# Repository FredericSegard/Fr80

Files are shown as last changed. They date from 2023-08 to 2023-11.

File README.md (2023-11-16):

# Fr80

 ## Z80 Homebrew computer, code-named Fr80, pronounced Freddy.
This repo will contain all the elements for a complete Z80 system (Work in progress)

### The Backplane:
The goal is to first make a ubiquitous backplane that could accommodate many 8 or 16-bit architectures, including most x86 that is compatible, Z80, eZ80, z8000, 65C02, 65C816, 6809... You name it, it should handle it. The only difference is in the PCB labeling. I have labeled the breadboard header as per the PC ISA standard on row 1, row 2 is for the Z80, and row 3 is for the 65C02. The breadboard pins are pin-to-pin mapped A1-A13 on the left, and B1-B31 on the right.
 
This backplane follows the ISA power rail standard. This means the +5, ground, +12V, and -12V lanes are where they should be. However, there is provision for a -5V regulator, since most ATX PSUs no longer support it. And since 3.3V is more prevalent these days, I have assigned the -5V lane to +3.3V. However, you can select which voltage you need by simply changing a jumper's position. There is an alternate barrel jack power input for 5 volts only. There is a provision for a 3.3V regulator should you need it. Both power sources are soft power-on. Jumpers are present to repurpose the button, since electrically, they could not be tied together.

It is a passive backplane, so there should be no interference with other signal types. So in theory, you could reassign all non-power rail buses, except for the reset lane and A7 and A8. The reset circuit, which is jumper selectable between active high or active low, cannot be reassigned. And the CPU activity LED, which monitors A7 or A8 (jumper selectable), can't also be moved.

I have just received the PCBs from the fab house. I will assemble it and let you know if everything works as intended.

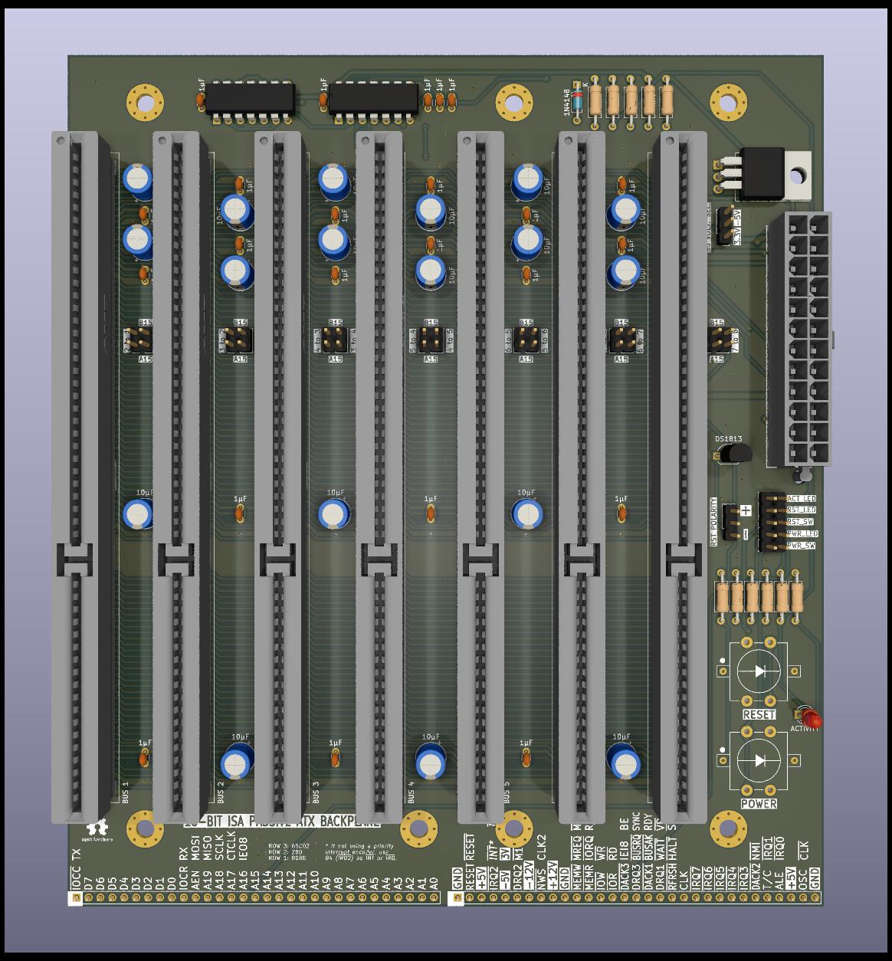
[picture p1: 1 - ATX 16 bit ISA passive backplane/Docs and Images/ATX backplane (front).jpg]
Front of board


### The Core CPU card:
I made several iterations of the CPU board, but now I'm satisfied with this revision 3. It's a very compact 100mm² 4-layer board, that contains the CPU, 128KB Flash, 512KM RAM, bank switching circuitry, a priority interrupt encoder, a CTC, and an SIO with USB ports (type A and type B).

I gave myself a challenge to fit as much as possible in a 100mm² PCB, all the while managing to put in a ZIF socket and some blinkenlights. The board is so stuffed with components, that I needed to place the bypass capacitors in the sockets, as well as some resistors. 

I will send out the Gerber for manufacturing, and keep you posted.

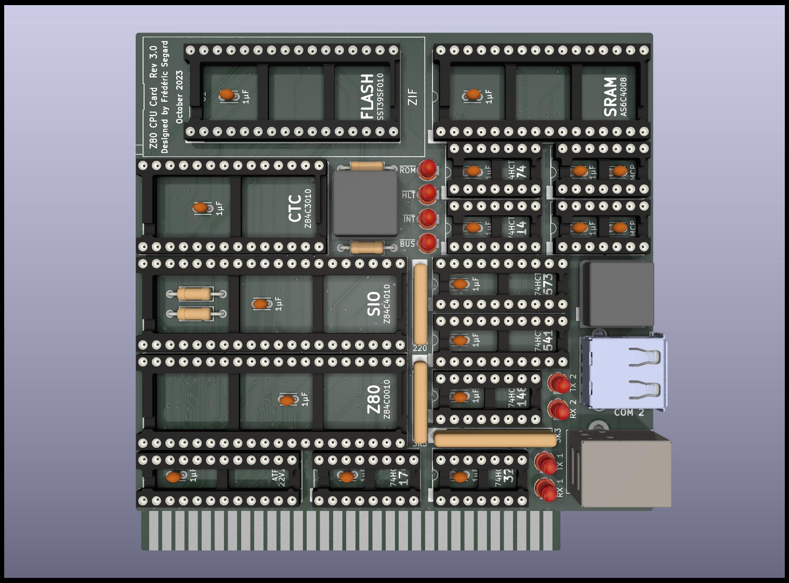
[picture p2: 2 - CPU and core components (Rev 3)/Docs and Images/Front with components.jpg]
Front of board


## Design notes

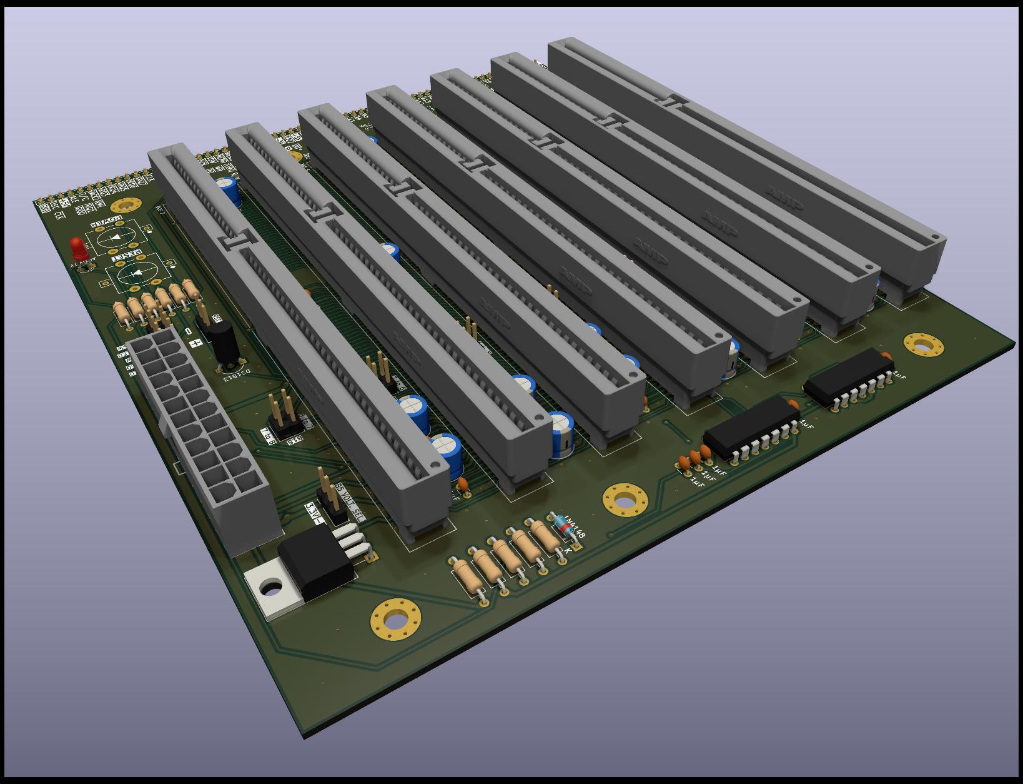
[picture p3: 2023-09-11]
1 - ATX 16 bit ISA passive backplane/Docs and Images/ATX backplane (view2).jpg

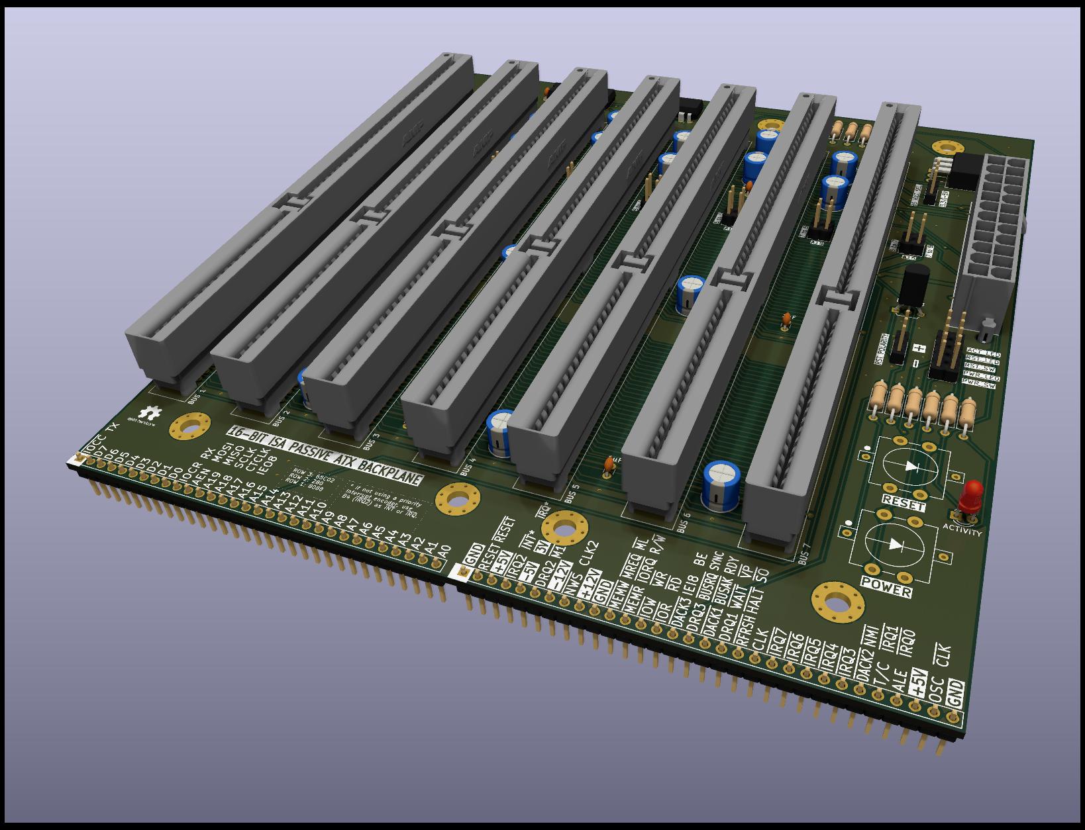
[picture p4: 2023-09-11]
1 - ATX 16 bit ISA passive backplane/Docs and Images/ATX backplane (view1).jpg

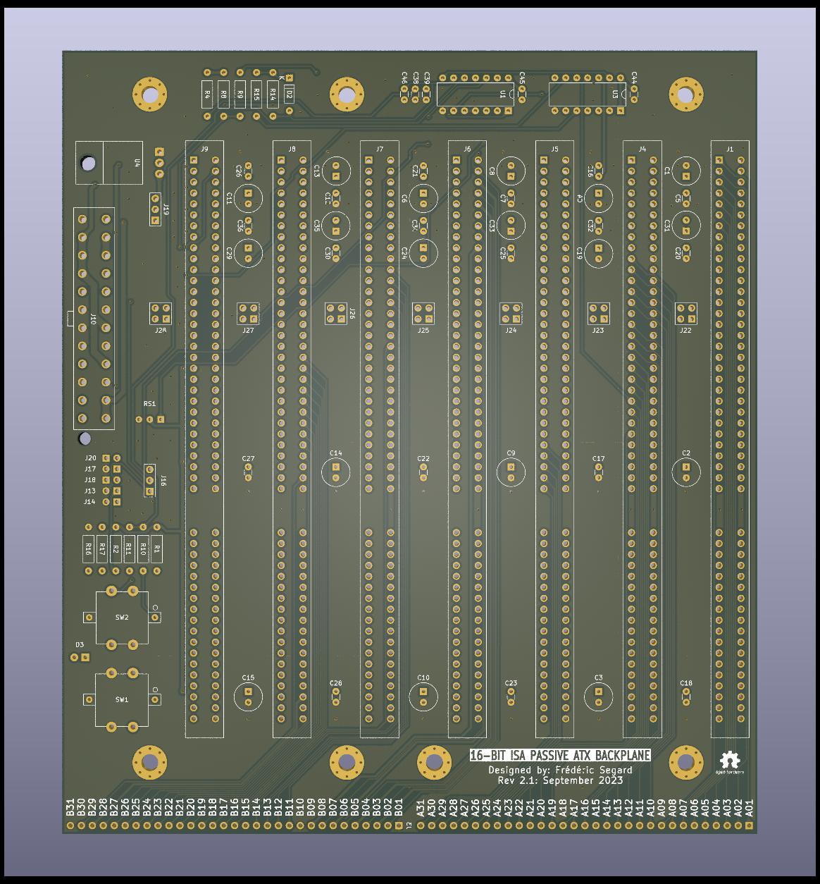
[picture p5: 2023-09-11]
1 - ATX 16 bit ISA passive backplane/Docs and Images/ATX backplane (back).jpg

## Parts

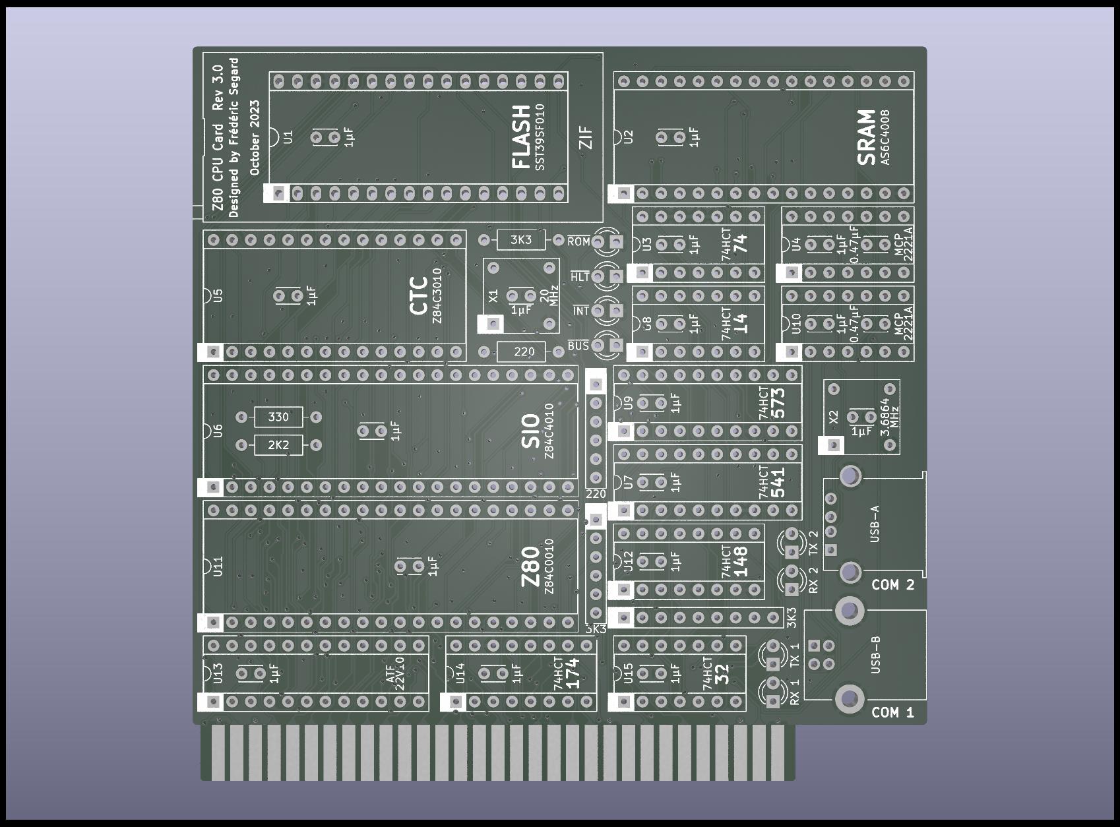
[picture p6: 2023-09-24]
2 - CPU and core components (Rev 3)/Docs and Images/Front without components.jpg

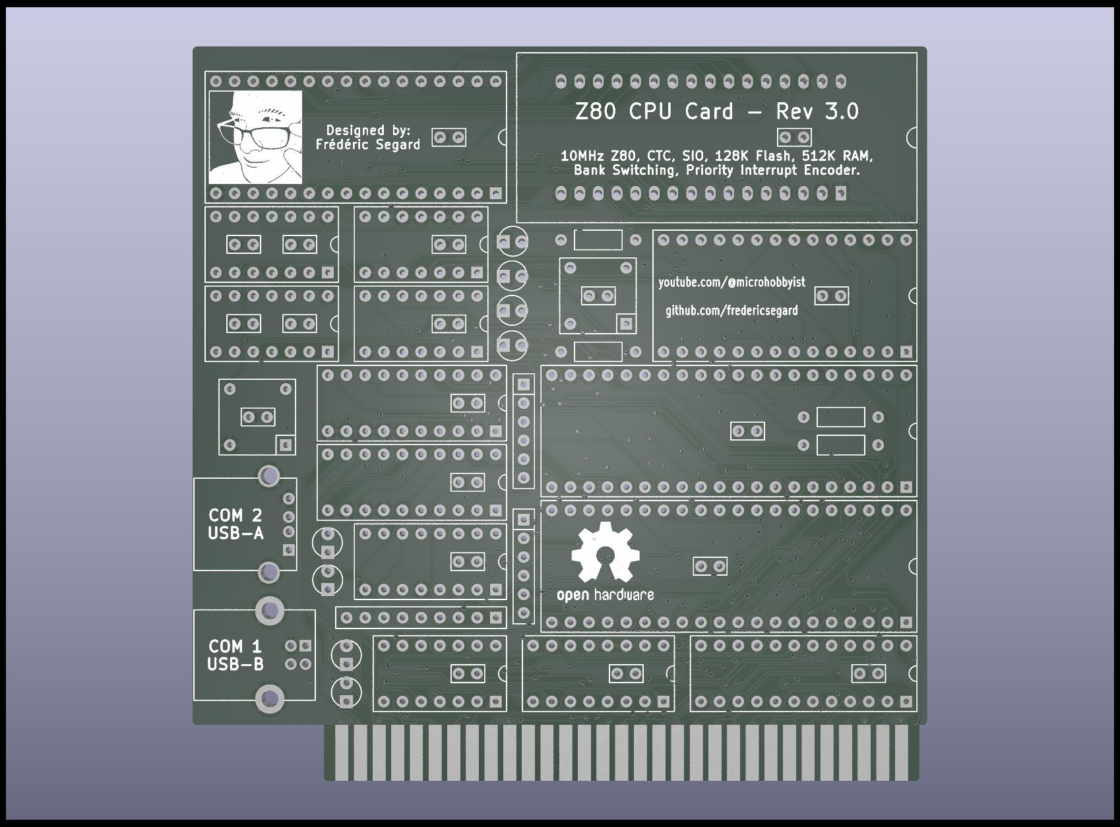
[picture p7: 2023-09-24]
2 - CPU and core components (Rev 3)/Docs and Images/Back.jpg

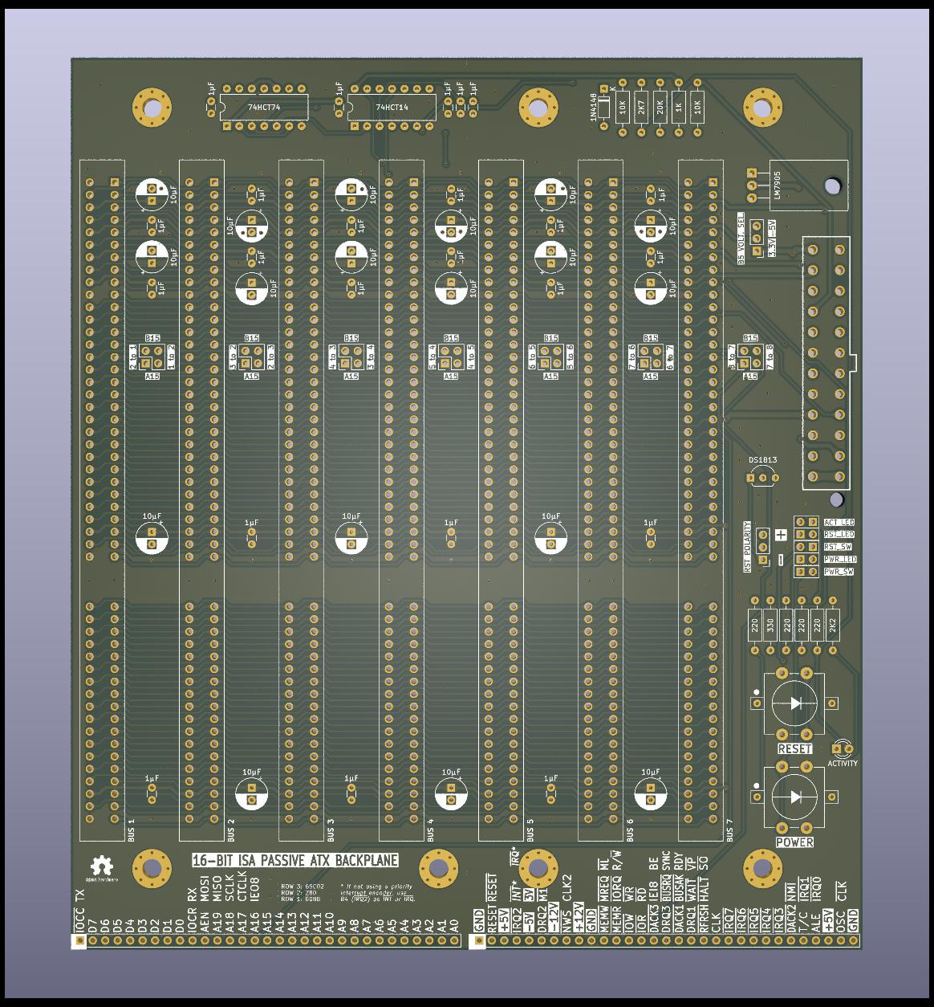
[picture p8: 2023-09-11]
1 - ATX 16 bit ISA passive backplane/Docs and Images/ATX backplane (front without parts).jpg

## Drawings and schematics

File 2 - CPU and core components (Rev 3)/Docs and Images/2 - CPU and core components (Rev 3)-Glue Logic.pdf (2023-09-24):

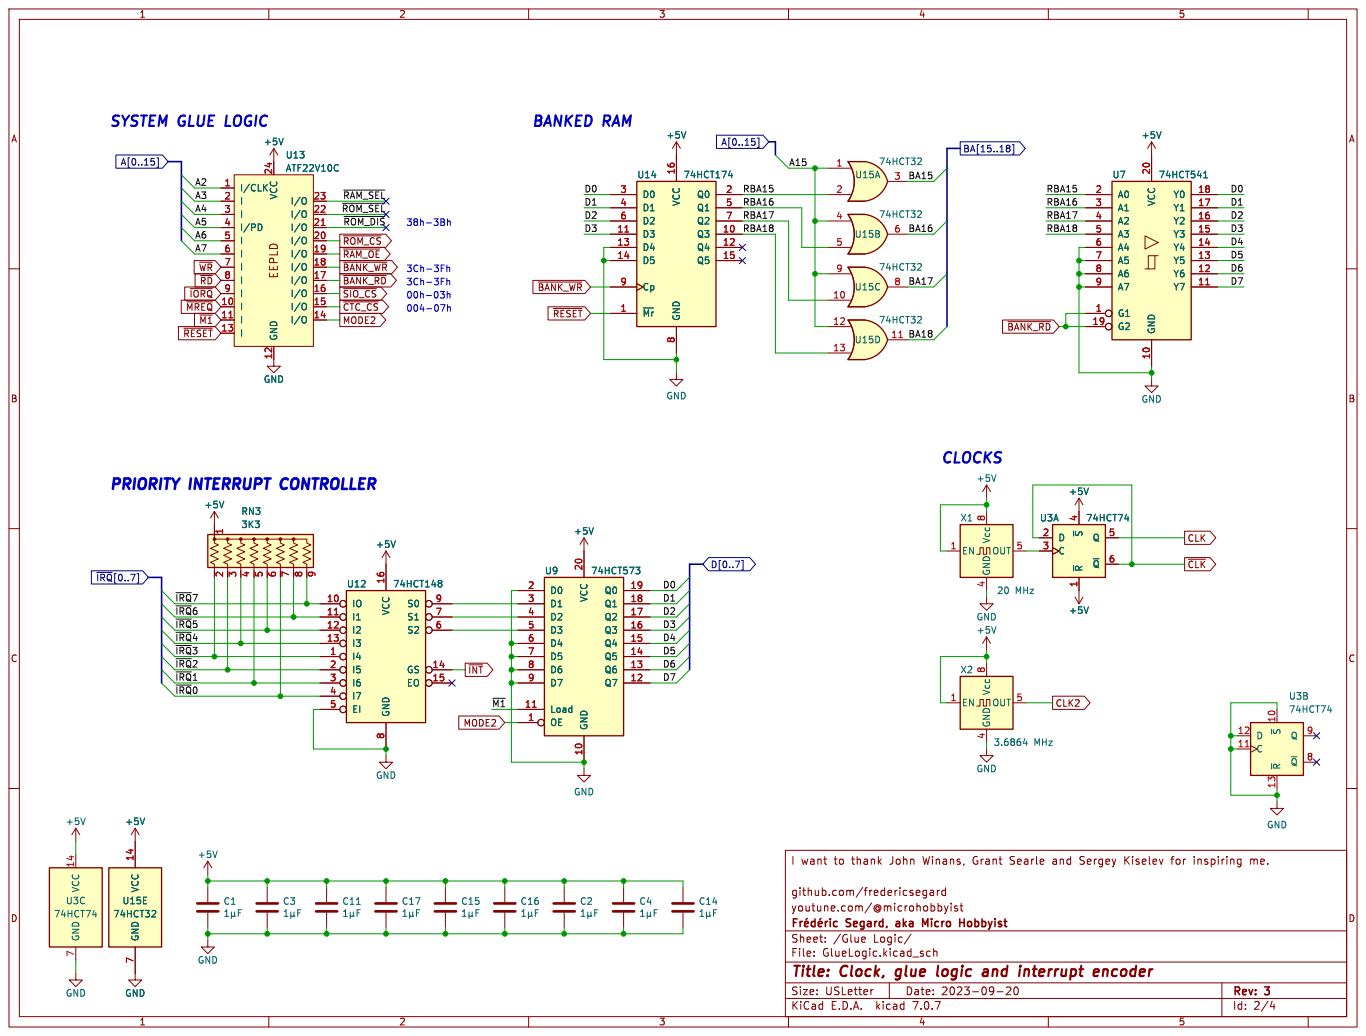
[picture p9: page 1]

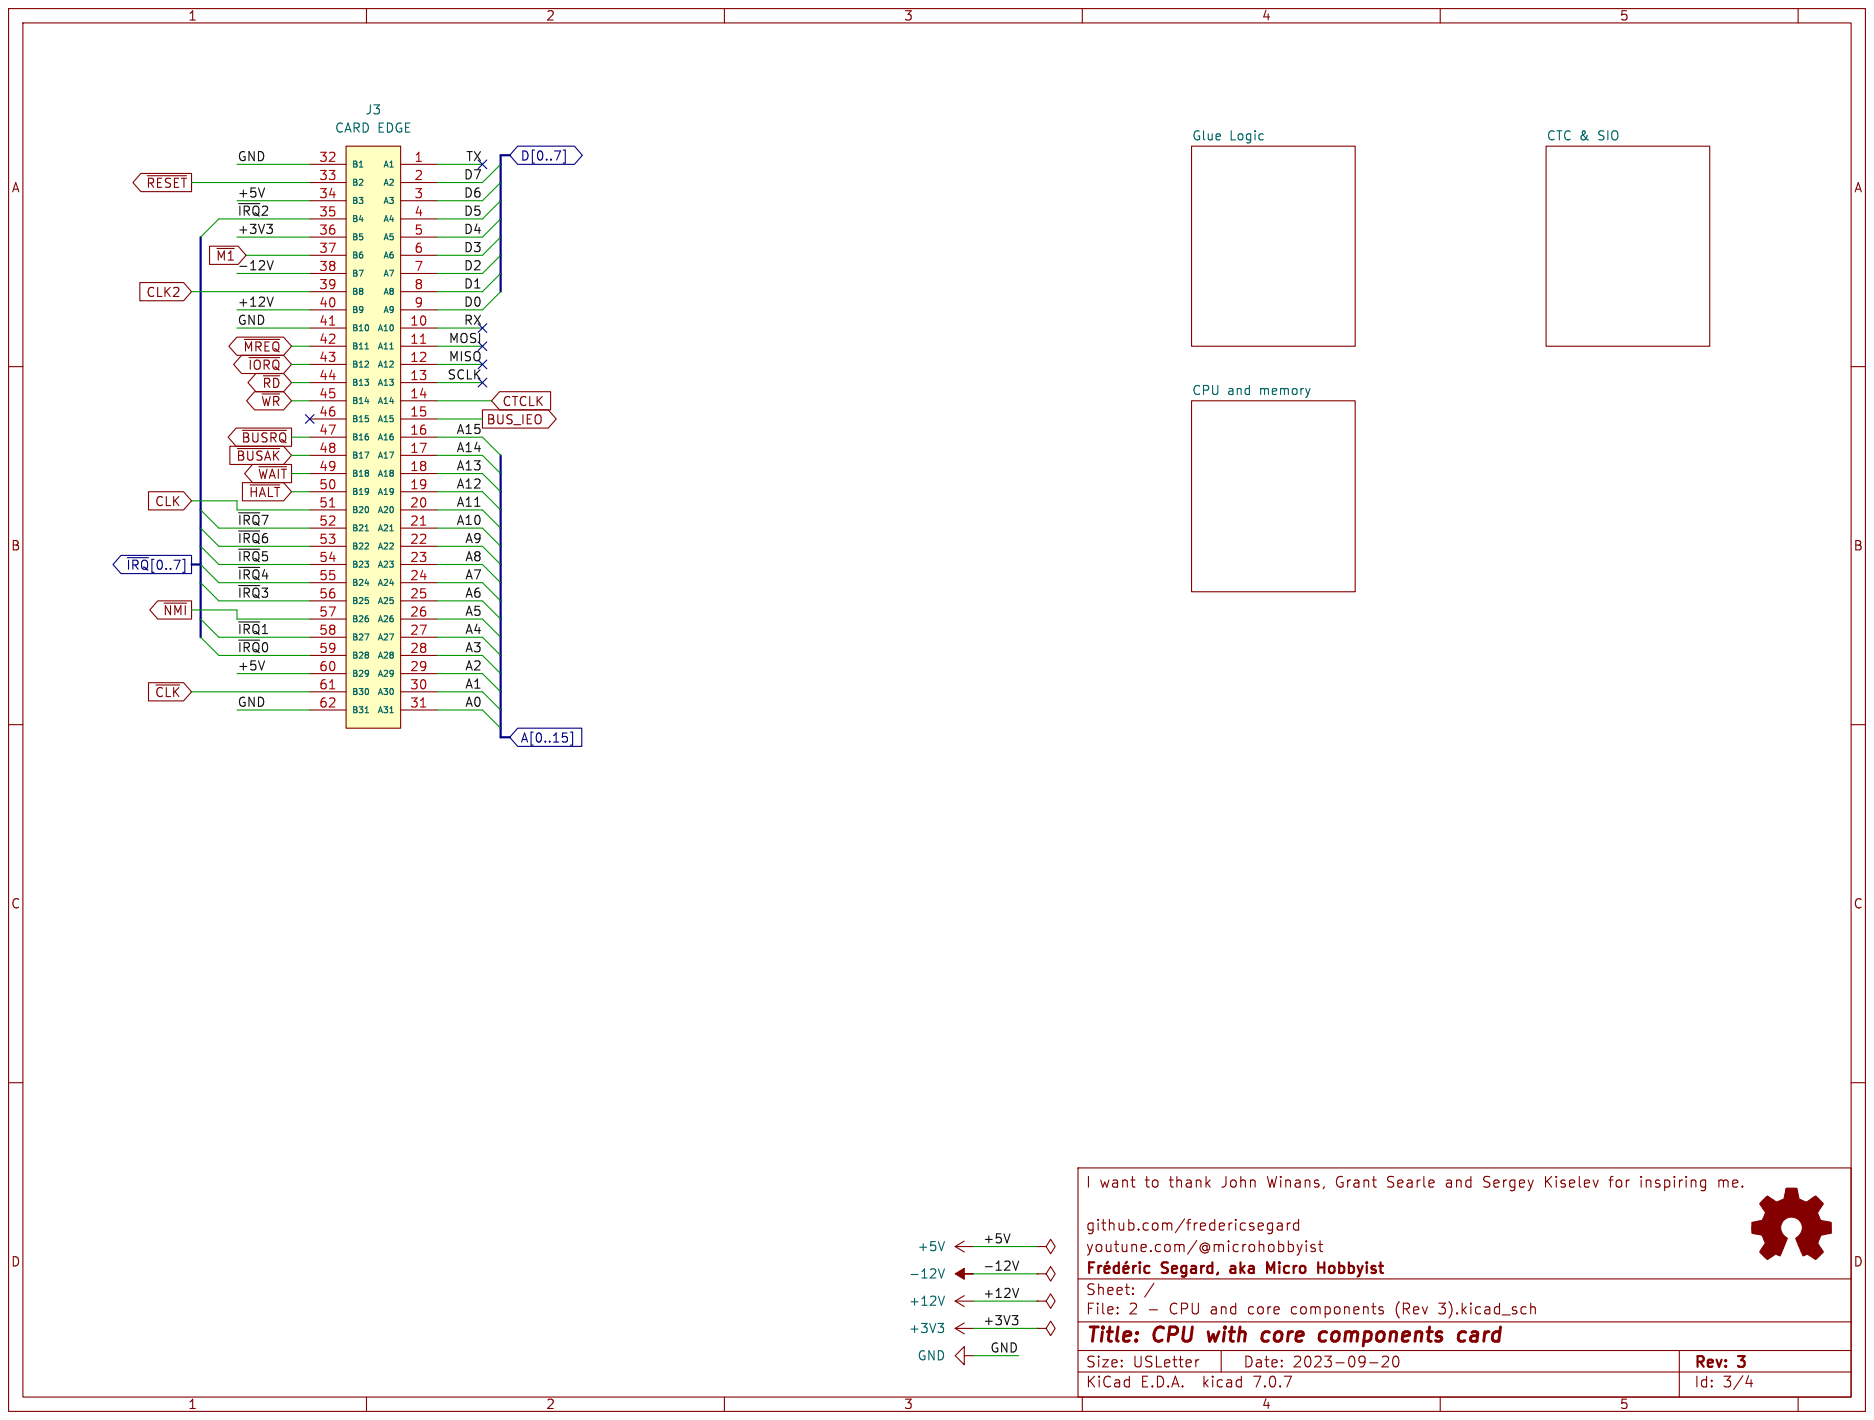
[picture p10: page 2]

Id: 3/4 Title: CPU with core components card

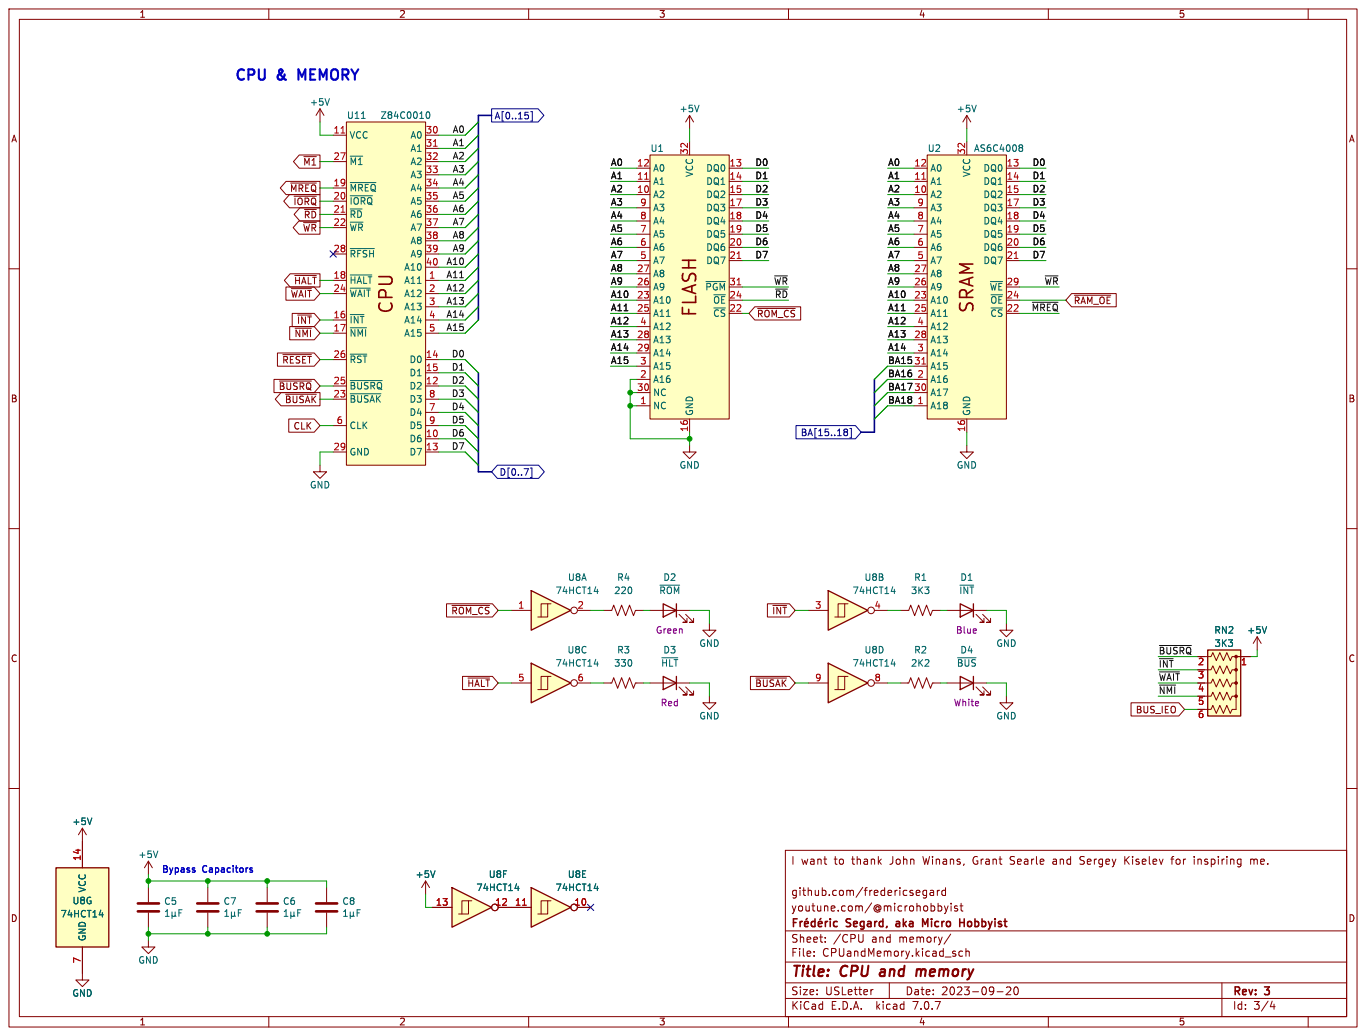
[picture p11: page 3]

github.com/fredericsegard
youtune.com/@microhobbyist
Id: 3/4 Title: CPU and memory

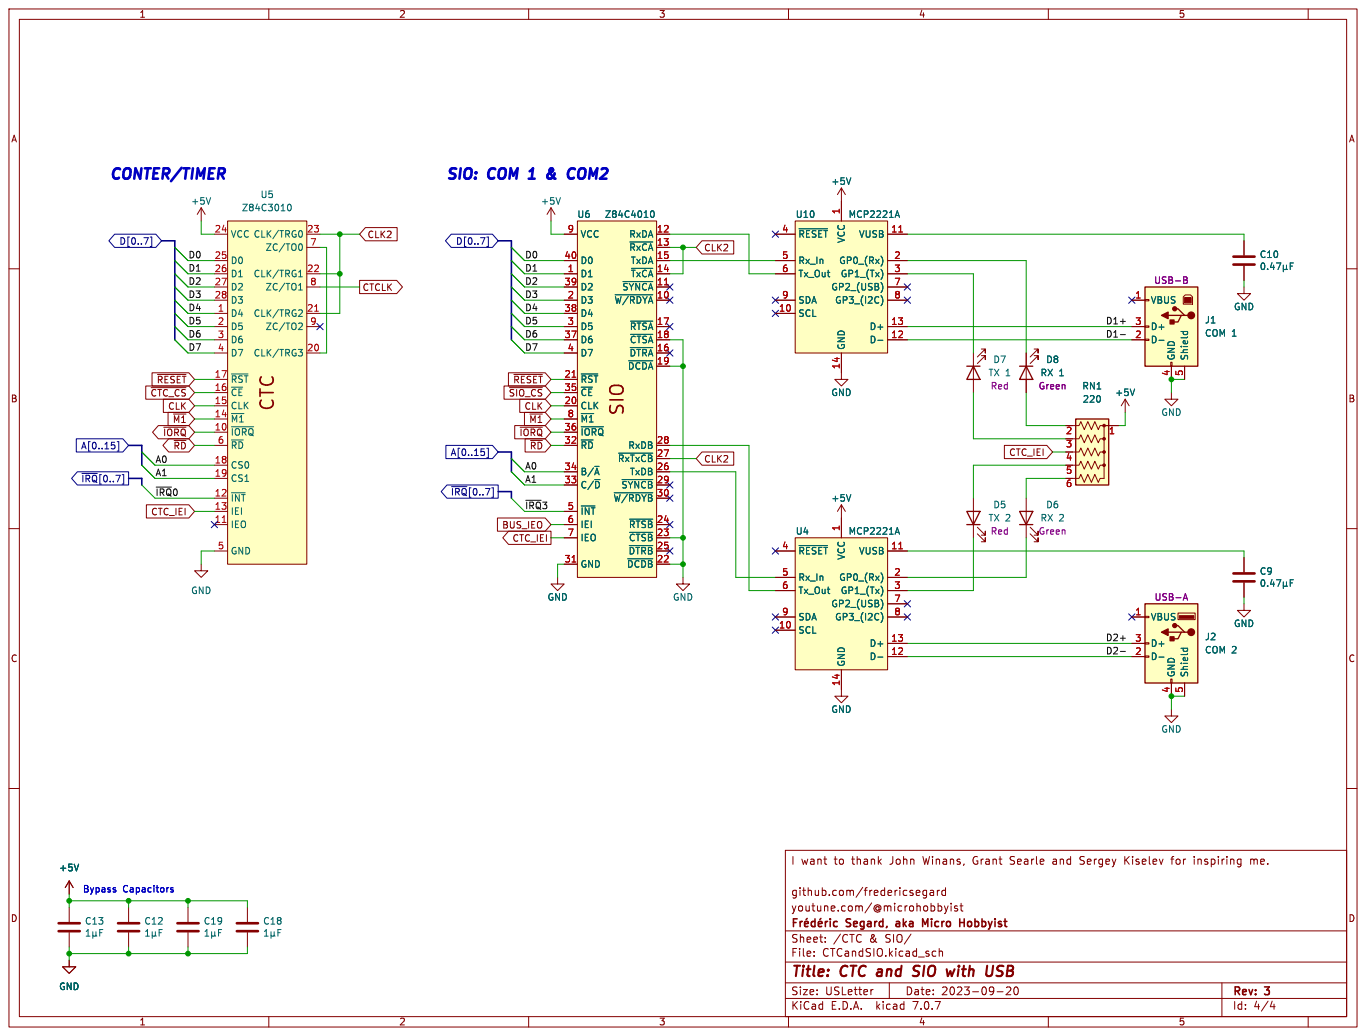
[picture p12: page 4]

þÿ0.47µF D8 RX 1 Green GND

Id: 4/4 Title: CTC and SIO with USB

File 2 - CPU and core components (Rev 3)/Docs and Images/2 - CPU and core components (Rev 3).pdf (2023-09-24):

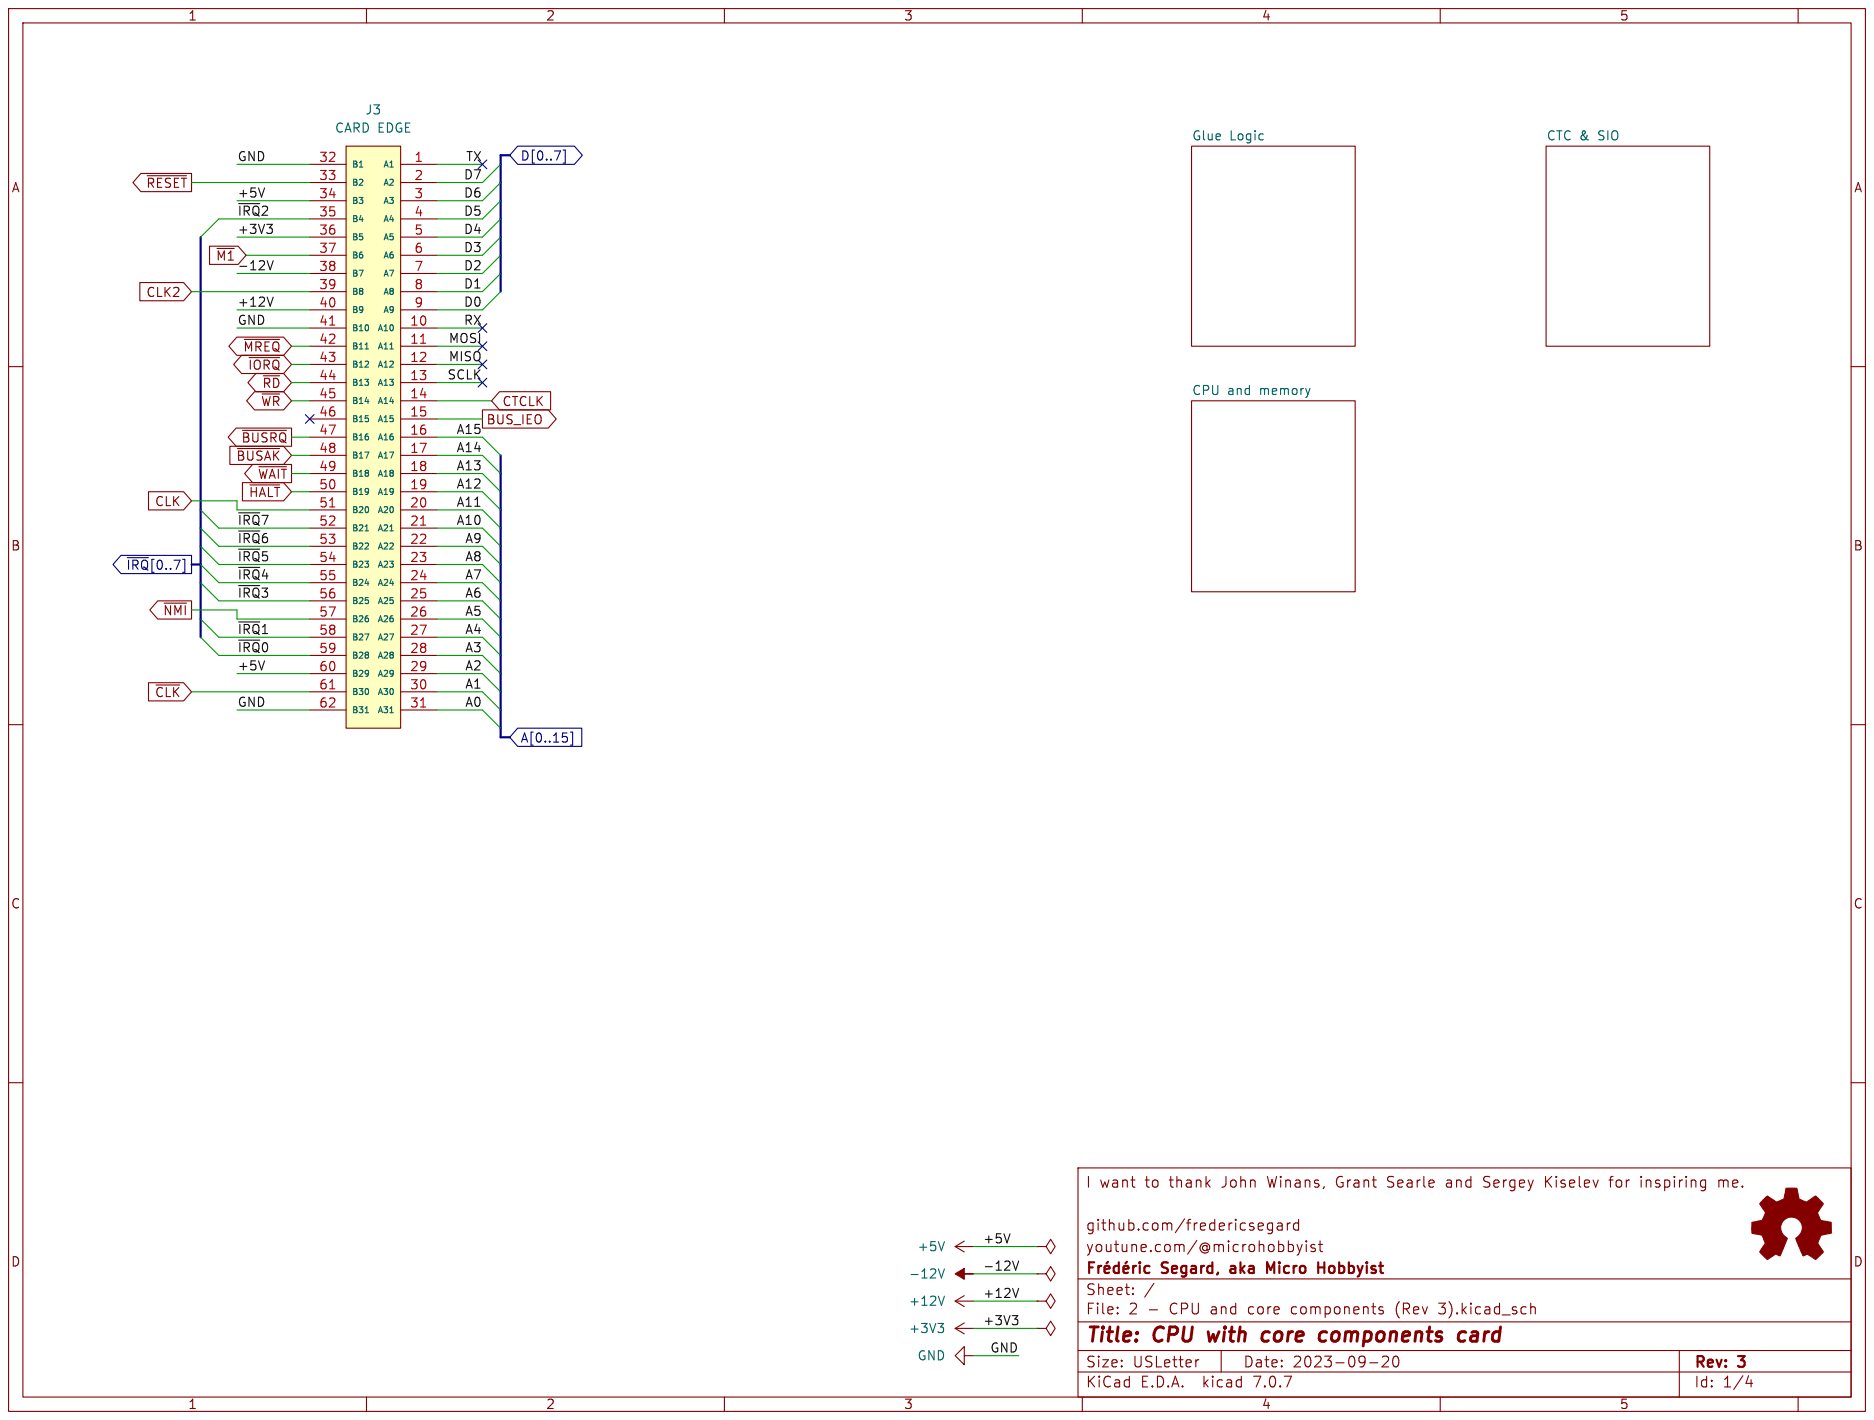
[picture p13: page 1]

Id: 1/4 Title: CPU with core components card

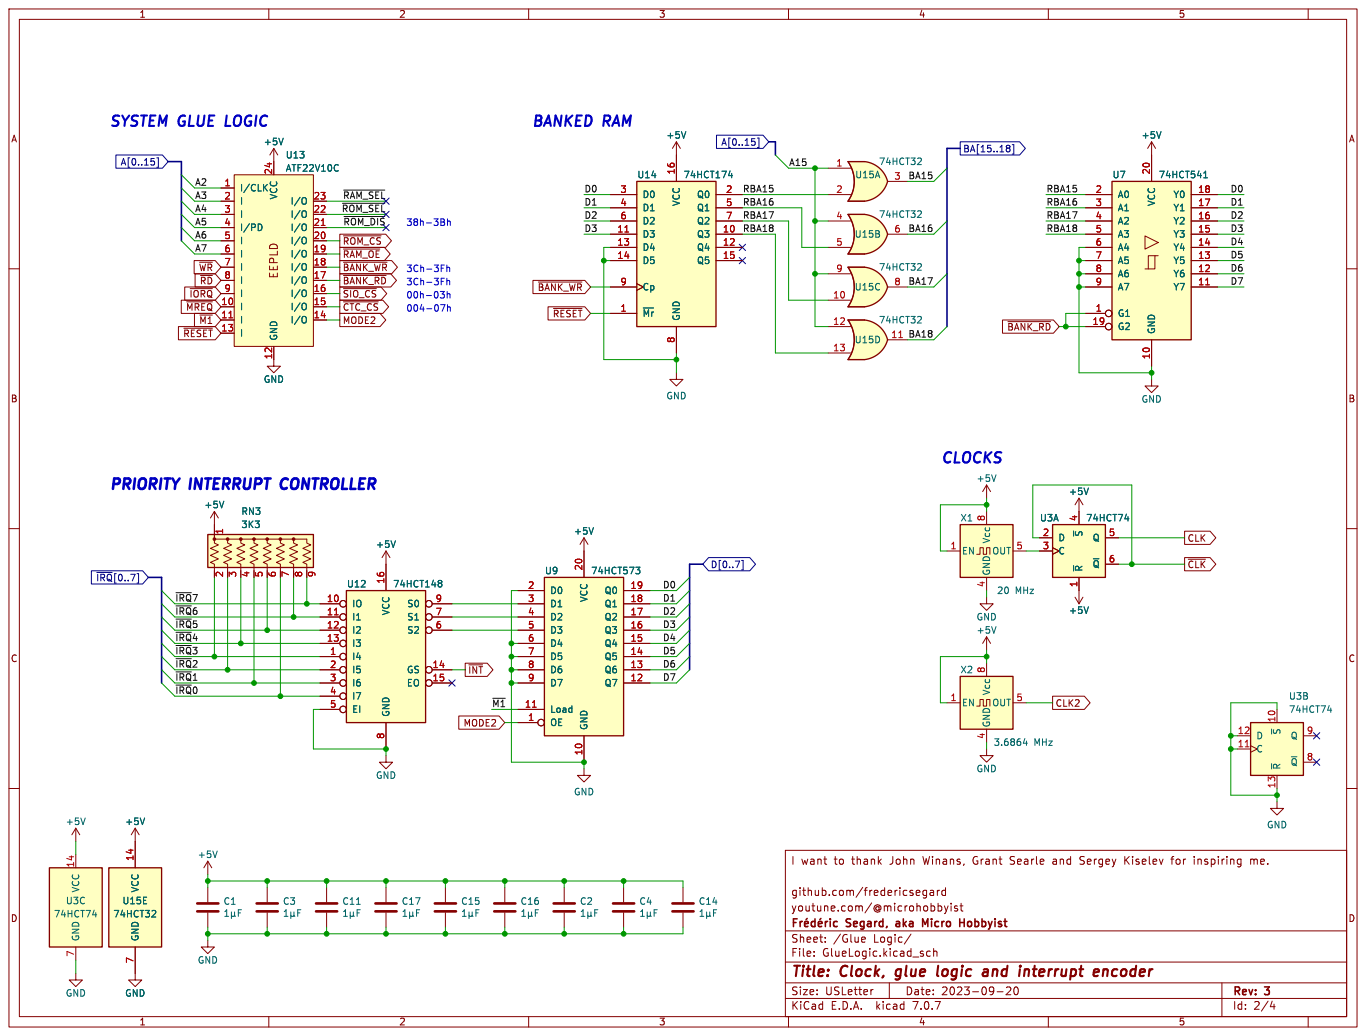
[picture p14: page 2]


github.com/fredericsegard
youtune.com/@microhobbyist
Id: 3/4 Title: CPU and memory


þÿ0.47µF D8 RX 1 Green GND

Id: 4/4 Title: CTC and SIO with USB

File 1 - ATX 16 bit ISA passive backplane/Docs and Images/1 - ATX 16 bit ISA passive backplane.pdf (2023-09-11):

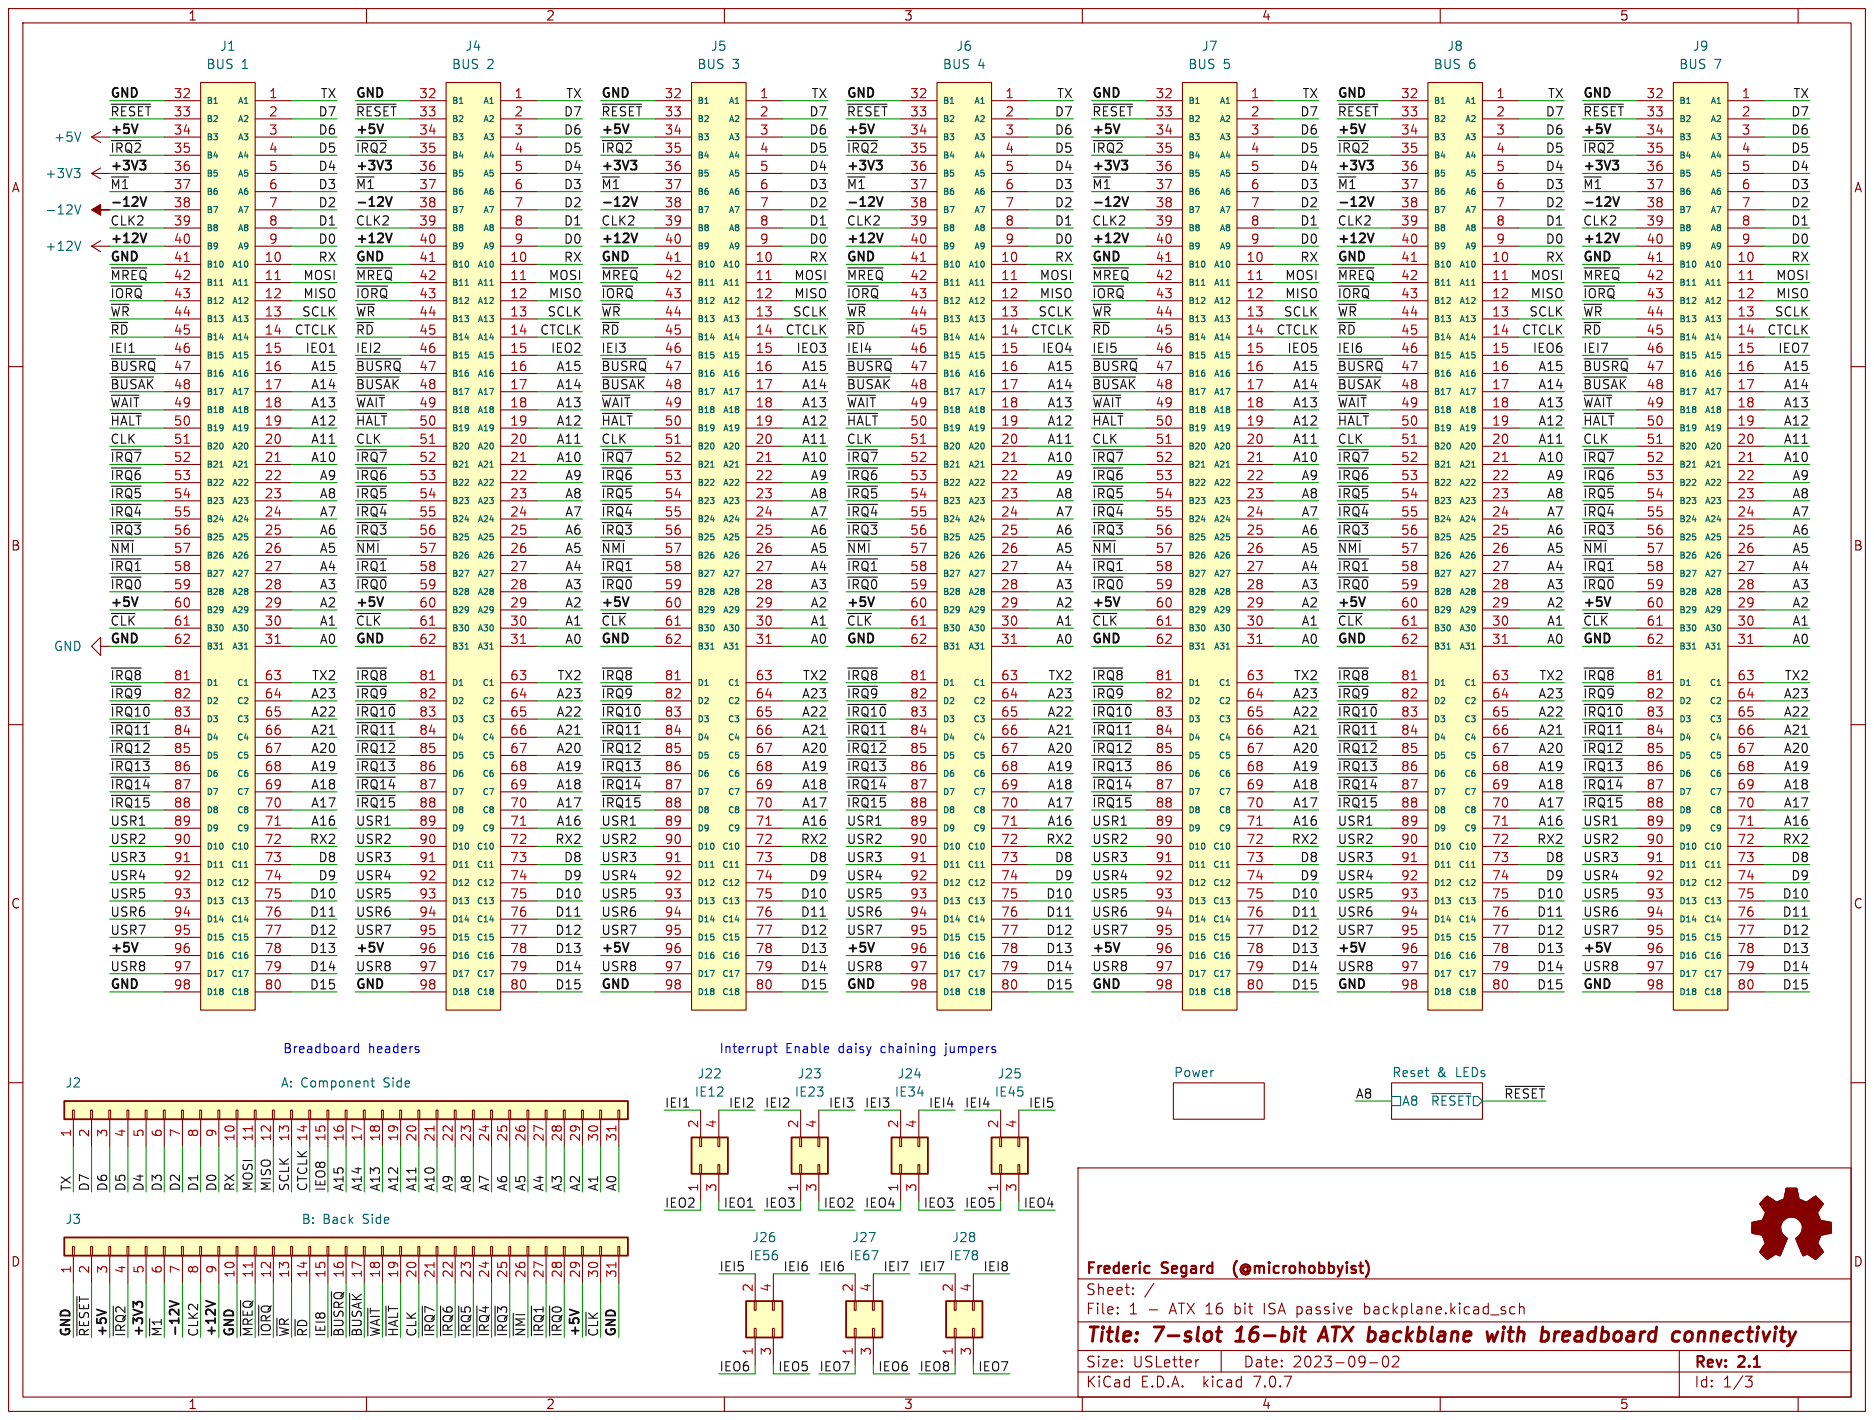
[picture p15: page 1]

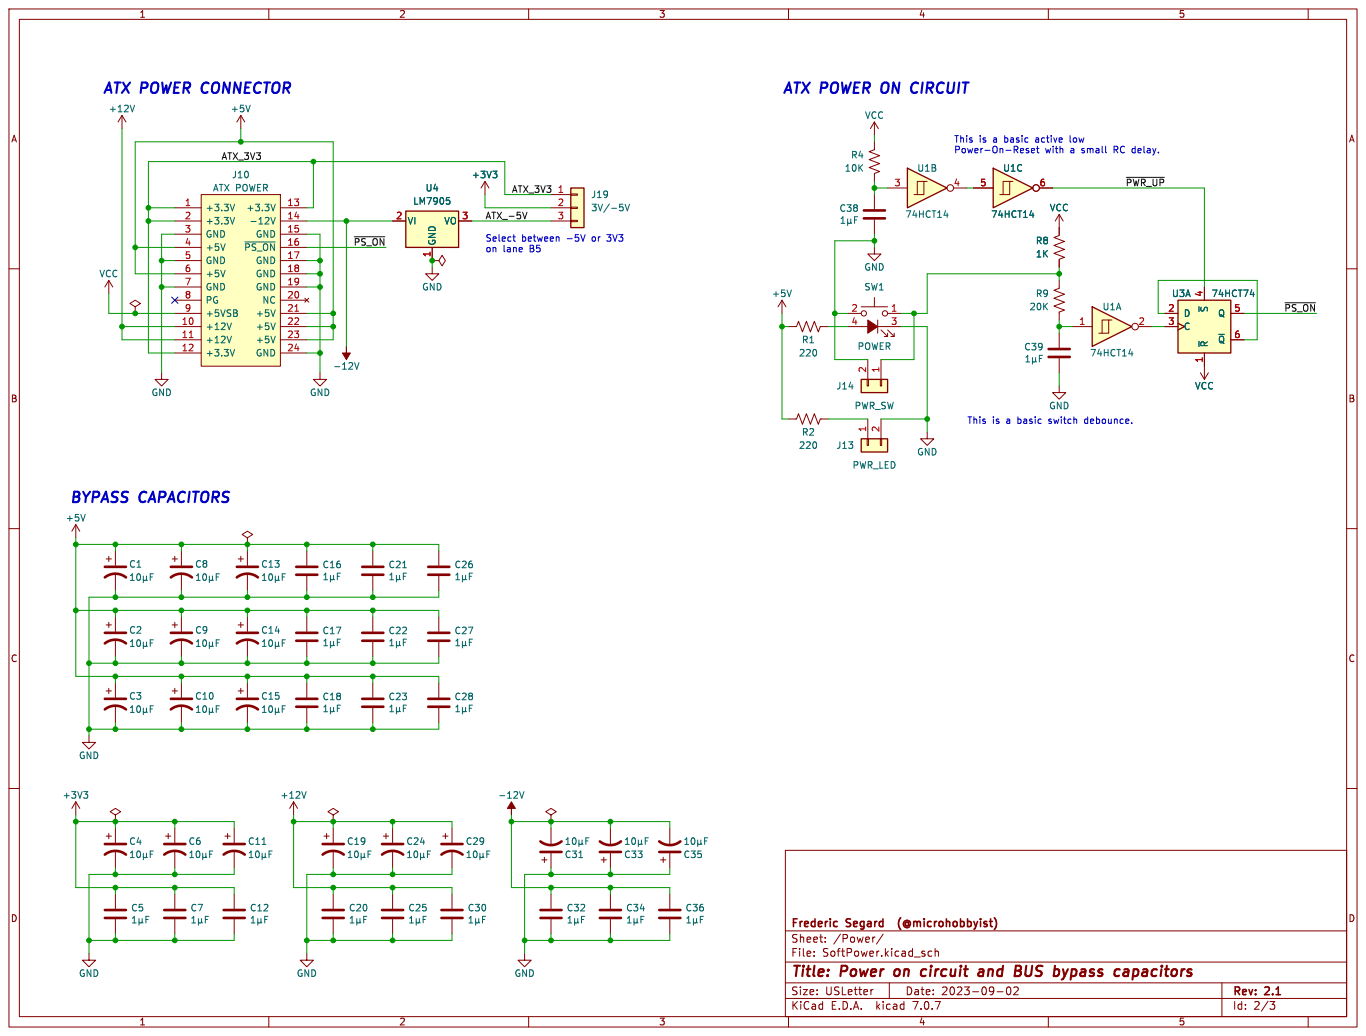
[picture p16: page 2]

This is a basic switch debounce. ATX POWER ON CIRCUIT

Id: 2/3 Title: Power on circuit and BUS bypass capacitors

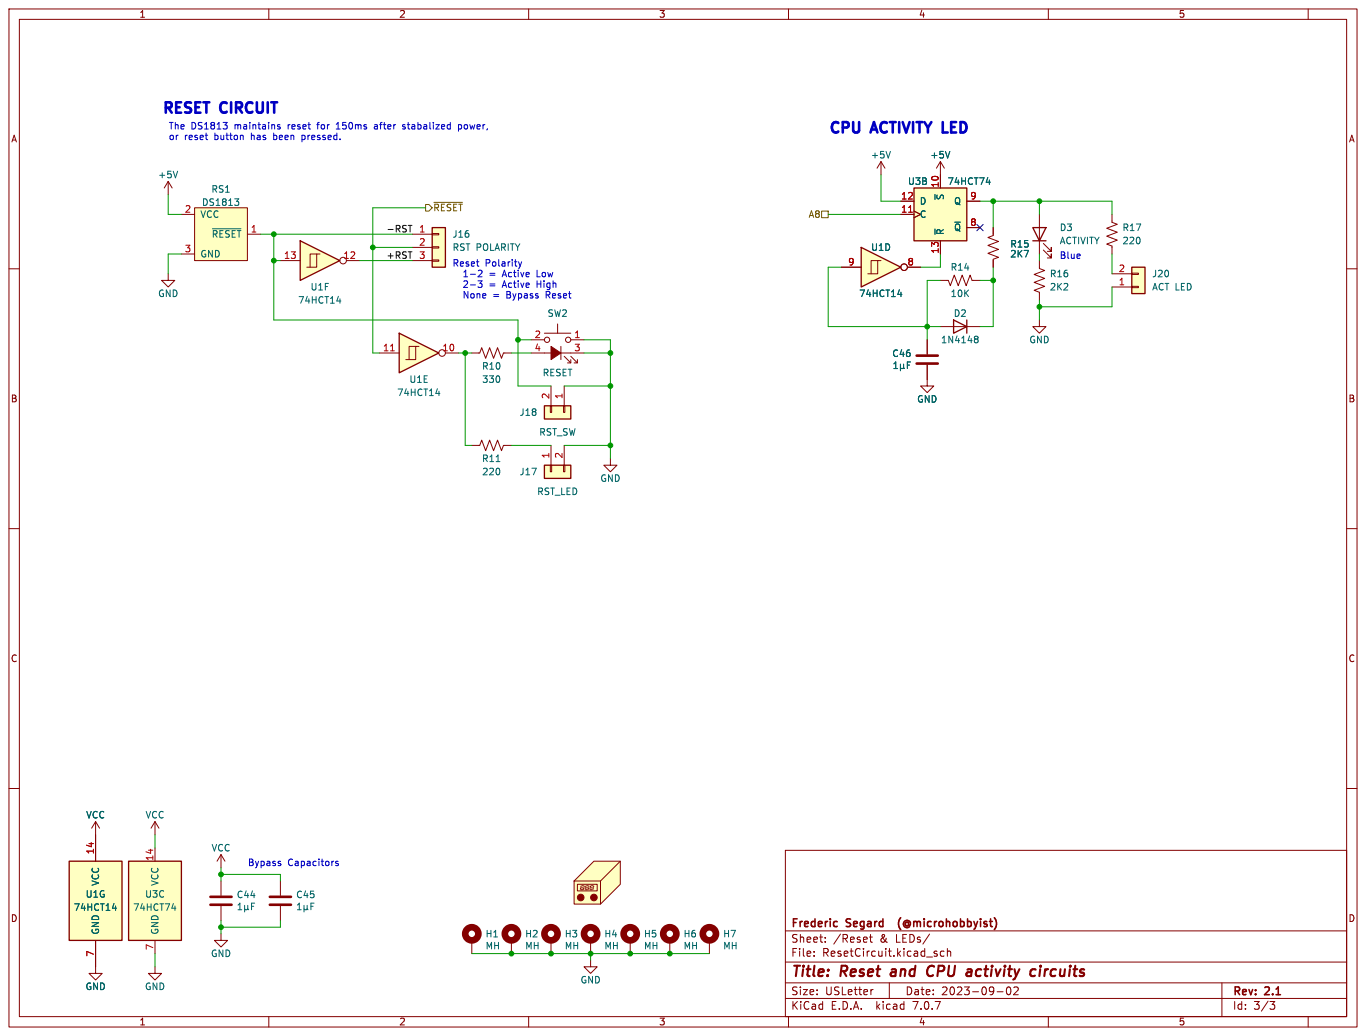
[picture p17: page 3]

Id: 3/3 Title: Reset and CPU activity circuits

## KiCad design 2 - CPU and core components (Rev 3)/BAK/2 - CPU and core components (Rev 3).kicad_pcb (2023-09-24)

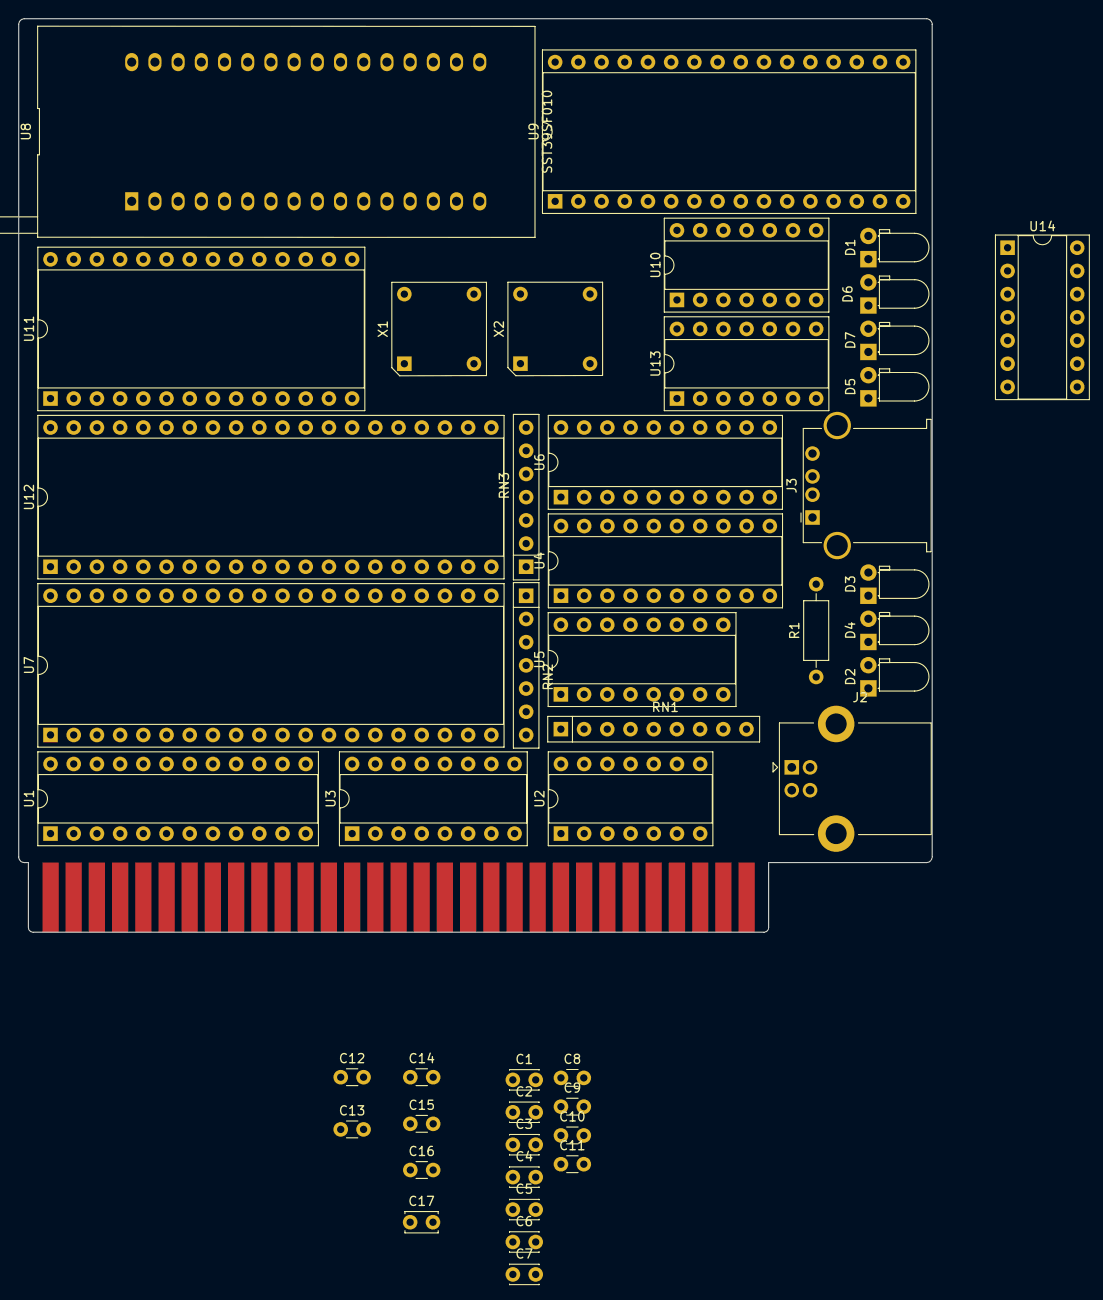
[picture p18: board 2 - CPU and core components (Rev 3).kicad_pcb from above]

Board: 2 copper layers, 100.0 x 100.0 mm, 47 parts (0 on the bottom side), 95 nets, no tracks yet.

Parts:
C1, C2, C3, C4, C5, C6, C7: 1µF; C_Disc_D3.0mm_W2.0mm_P2.50mm
C8, C9, C10, C11, C14, C15, C16: 1µF; C_Disc_D3.0mm_W1.6mm_P2.50mm
C12, C13: 0.47µF; C_Disc_D3.0mm_W1.6mm_P2.50mm
C17: 1µF; C_Disc_D3.4mm_W2.1mm_P2.50mm
D1: STATUS; LED_D3.0mm_Horizontal_O1.27mm_Z2.0mm
D2: USB 1; LED_D3.0mm_Horizontal_O1.27mm_Z2.0mm
D3: TX 1; LED_D3.0mm_Horizontal_O1.27mm_Z2.0mm
D4: RX 1; LED_D3.0mm_Horizontal_O1.27mm_Z2.0mm
D5: USB 2; LED_D3.0mm_Horizontal_O1.27mm_Z2.0mm
D6: TX 2; LED_D3.0mm_Horizontal_O1.27mm_Z2.0mm
D7: RX 2; LED_D3.0mm_Horizontal_O1.27mm_Z2.0mm
J1: CARD EDGE; BUS_XT v2
J2: COM 1; USB_B_Lumberg_2411_02_Horizontal
J3: COM 2; USB_A_Stewart_SS-52100-001_Horizontal
R1: 3K3; R_Axial_DIN0207_L6.3mm_D2.5mm_P10.16mm_Horizontal
RN1: 3K3; R_Array_SIP9
RN2, RN3: 3K3; R_Array_SIP7
U1: ATF22V10C; DIP-24_W7.62mm_Socket
U2: 74HCT32; DIP-14_W7.62mm_Socket
U3: 74LS174; DIP-16_W7.62mm_Socket
U4: 74HCT541; DIP-20_W7.62mm_Socket
U5: 74HCT148; DIP-16_W7.62mm_Socket
U6: 74HCT573; DIP-20_W7.62mm_Socket
U7: Z84C0010; DIP-40_W15.24mm_Socket
U8: SST39SF010; ZIF_Socket-32
U9: AS6C4008; DIP-32_W15.24mm_Socket
U10: 74HCT30; DIP-14_W7.62mm_Socket
U11: Z84C3010; DIP-28_W15.24mm_Socket
U12: Z84C4010; DIP-40_W15.24mm_Socket
U13, U14: MCP2221A; DIP-14_W7.62mm_Socket
X1: 10 MHz; DIP-8-4_W7.62mm_Oscillator_Socket
X2: 3.6864 MHz; DIP-8-4_W7.62mm_Oscillator_Socket

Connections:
+5V: C1.1, C2.1, C3.1, C4.1, C5.1, C6.1, C7.1, C8.1, C9.1, C10.1, C11.1, C14.1, C15.1, C16.1, C17.1, J1.34 (B3), J1.60 (B29), RN1.1 (common), RN2.1 (common), RN3.1 (common), U1.24 (VCC), U2.14 (VCC), U3.16 (VCC), U4.20 (VCC), U5.16 (VCC), U6.20 (VCC), U7.11 (VCC), U8.32 (VCC), U9.32 (VCC), U10.14 (VCC), U11.24 (VCC), U12.9 (VCC), U13.1 (VCC), U14.1 (VCC), X1.1 (EN), X1.8 (Vcc), X2.1 (EN), X2.8 (Vcc)
/CTC & SIO/D1+: J2.3 (D+), U13.13 (D+)
/CTC & SIO/D1-: J2.2 (D-), U13.12 (D-)
/CTC & SIO/D2+: J3.3 (D+), U14.13 (D+)
/CTC & SIO/D2-: J3.2 (D-), U14.12 (D-)
/GND: J1.32 (B1), J1.41 (B10), J1.62 (B31)
/Glue Logic/RBA15: U2.2, U3.2 (Q0), U4.2 (A0)
/Glue Logic/RBA16: U2.5, U3.5 (Q1), U4.3 (A1)
/Glue Logic/RBA17: U2.10, U3.7 (Q2), U4.4 (A2)
/Glue Logic/RBA18: U2.13, U3.10 (Q3), U4.5 (A3)
A0: J1.31 (A31), U7.30 (A0), U8.12 (A0), U9.12 (A0), U11.18 (CS0), U12.34 (B/~A)
A1: J1.30 (A30), U7.31 (A1), U8.11 (A1), U9.11 (A1), U11.19 (CS1), U12.33 (C/~D)
A2: J1.29 (A29), U1.7 (I), U7.32 (A2), U8.10 (A2), U9.10 (A2)
A3: J1.28 (A28), U1.8 (I), U7.33 (A3), U8.9 (A3), U9.9 (A3)
A4: J1.27 (A27), U1.9 (I), U7.34 (A4), U8.8 (A4), U9.8 (A4)
A5: J1.26 (A26), U1.10 (I), U7.35 (A5), U8.7 (A5), U9.7 (A5)
A6: J1.25 (A25), U1.11 (I), U7.36 (A6), U8.6 (A6), U9.6 (A6)
A7: J1.24 (A24), U1.13 (I), U7.37 (A7), U8.5 (A7), U9.5 (A7)
A8: J1.23 (A23), U7.38 (A8), U8.27 (A8), U9.27 (A8)
A9: J1.22 (A22), U7.39 (A9), U8.26 (A9), U9.26 (A9)
A10: J1.21 (A21), U7.40 (A10), U8.23 (A10), U9.23 (A10)
A11: J1.20 (A20), U7.1 (A11), U8.25 (A11), U9.25 (A11)
A12: J1.19 (A19), U7.2 (A12), U8.4 (A12), U9.4 (A12)
A13: J1.18 (A18), U7.3 (A13), U8.28 (A13), U9.28 (A13)
A14: J1.17 (A17), U7.4 (A14), U8.29 (A14), U9.3 (A14)
A15: J1.16 (A16), U2.1, U2.4, U2.9, U2.12, U7.5 (A15), U8.3 (A15)
BA15: U2.3, U9.31 (A15)
BA16: U2.6, U9.2 (A16)
BA17: U2.8, U9.30 (A17)
BA18: U2.11, U9.1 (A18)
BUS_IEO: J1.15 (A15), RN2.6 (R5), U12.6 (IEI)
CLK: J1.51 (B20), U7.6 (CLK), U11.15 (CLK), U12.20 (CLK), X1.5 (OUT)
CLK2: J1.39 (B8), U11.21 (CLK/TRG2), U11.22 (CLK/TRG1), U11.23 (CLK/TRG0), U12.13 (~RxCA), U12.14 (~TxCA), U12.27 (~RxTxCB), X2.5 (OUT)
CTCLK: J1.14 (A14), U11.8 (ZC/TO1)
CTC_IEI: RN2.7 (R6), U11.13 (IEI), U12.7 (IEO)
D0: J1.9 (A9), U3.3 (D0), U4.18 (Y0), U6.19 (Q0), U7.14 (D0), U8.13 (DQ0), U9.13 (DQ0), U11.25 (D0), U12.40 (D0)
D1: J1.8 (A8), U3.4 (D1), U4.17 (Y1), U6.18 (Q1), U7.15 (D1), U8.14 (DQ1), U9.14 (DQ1), U11.26 (D1), U12.1 (D1)
D2: J1.7 (A7), U3.6 (D2), U4.16 (Y2), U6.17 (Q2), U7.12 (D2), U8.15 (DQ2), U9.15 (DQ2), U11.27 (D2), U12.39 (D2)
D3: J1.6 (A6), U3.11 (D3), U4.15 (Y3), U6.16 (Q3), U7.8 (D3), U8.17 (DQ3), U9.17 (DQ3), U11.28 (D3), U12.2 (D3)
D4: J1.5 (A5), U4.14 (Y4), U6.15 (Q4), U7.7 (D4), U8.18 (DQ4), U9.18 (DQ4), U11.1 (D4), U12.38 (D4)
D5: J1.4 (A4), U4.13 (Y5), U6.14 (Q5), U7.9 (D5), U8.19 (DQ5), U9.19 (DQ5), U11.2 (D5), U12.3 (D5)
D6: J1.3 (A3), U4.12 (Y6), U6.13 (Q6), U7.10 (D6), U8.20 (DQ6), U9.20 (DQ6), U11.3 (D6), U12.37 (D6)
D7: J1.2 (A2), U4.11 (Y7), U6.12 (Q7), U7.13 (D7), U8.21 (DQ7), U9.21 (DQ7), U11.4 (D7), U12.4 (D7)
GND: C1.2, C2.2, C3.2, C4.2, C5.2, C6.2, C7.2, C8.2, C9.2, C10.2, C11.2, C12.2, C13.2, C14.2, C15.2, C16.2, C17.2, D1.1 (K), J2.4 (GND), J2.5 (Shield), J3.4 (GND), J3.5 (Shield), U1.12 (GND), U2.7 (GND), U3.8 (GND), U3.13 (D4), U3.14 (D5), U4.6 (A4), U4.7 (A5), U4.8 (A6), U4.9 (A7), U4.10 (GND), U5.5 (EI), U5.8 (GND), U6.2 (D0), U6.6 (D4), U6.7 (D5), U6.8 (D6), U6.9 (D7), U6.10 (GND), U7.29 (GND), U8.1 (NC), U8.2 (A16), U8.16 (GND), U8.30 (NC), U9.16 (GND), U10.7 (GND), U11.5 (GND), U12.18 (~CTSA), U12.19 (~DCDA), U12.22 (~DCDB), U12.23 (~CTSB), U12.31 (GND), U13.14 (GND), U14.14 (GND), X1.4 (GND), X2.4 (GND)
MODE2: U1.14 (I/O), U6.1 (OE)
unnamed: D1.2 (A), R1.2
unnamed: D2.2 (A), RN3.4 (R3)
unnamed: D2.1 (K), U13.7 (GP2_(USB))
unnamed: D3.2 (A), RN3.3 (R2)
unnamed: D3.1 (K), U13.3 (GP1_(Tx))
unnamed: D4.2 (A), RN3.2 (R1)
unnamed: D4.1 (K), U13.2 (GP0_(Rx))
unnamed: D5.2 (A), RN3.5 (R4)
unnamed: D5.1 (K), U14.7 (GP2_(USB))
unnamed: D6.2 (A), RN3.6 (R5)
unnamed: D6.1 (K), U14.3 (GP1_(Tx))
unnamed: D7.2 (A), RN3.7 (R6)
unnamed: D7.1 (K), U14.2 (GP0_(Rx))
unnamed: R1.1, U10.8
unnamed: U5.9 (S0), U6.3 (D1)
unnamed: U5.7 (S1), U6.4 (D2)
unnamed: U5.6 (S2), U6.5 (D3)
unnamed: U11.7 (ZC/TO0), U11.20 (CLK/TRG3)
unnamed: U12.12 (RxDA), U13.6 (Tx_Out)
unnamed: U12.28 (RxDB), U14.6 (Tx_Out)
unnamed: U12.15 (TxDA), U13.5 (Rx_In)
unnamed: U12.26 (TxDB), U14.5 (Rx_In)
unnamed: C12.1, U13.11 (VUSB)
unnamed: C13.1, U14.11 (VUSB)
~BANK_RD: U1.17 (I/O), U4.1 (G1), U4.19 (G2)
~BANK_WR: U1.18 (I/O), U3.9 (Cp)
~BUSAK: J1.48 (B17), U7.23 (~BUSAK), U10.11
~BUSRQ: J1.47 (B16), RN2.2 (R1), U7.25 (~BUSRQ), U10.6
~CTC_CS: U1.15 (I/O), U11.16 (~CE)
~HALT: J1.50 (B19), U7.18 (~HALT), U10.2
~INT: RN2.3 (R2), U5.14 (GS), U7.16 (~INT), U10.4
~IORQ: J1.43 (B12), U1.3 (I), U7.20 (~IORQ), U11.10 (~IORQ), U12.36 (~IORQ)
~IRQ0: J1.59 (B28), RN1.7 (R6), U5.4 (I7), U11.12 (~INT)
~IRQ1: J1.58 (B27), RN1.5 (R4), U5.3 (I6)
~IRQ2: J1.35 (B4), RN1.3 (R2), U5.2 (I5)
~IRQ3: J1.56 (B25), RN1.2 (R1), U5.1 (I4), U12.5 (~INT)
~IRQ4: J1.55 (B24), RN1.4 (R3), U5.13 (I3)
~IRQ5: J1.54 (B23), RN1.6 (R5), U5.12 (I2)
~IRQ6: J1.53 (B22), RN1.8 (R7), U5.11 (I1)
~IRQ7: J1.52 (B21), RN1.9 (R8), U5.10 (IO)
~M1: J1.37 (B6), U1.6 (I), U6.11 (Load), U7.27 (~M1), U11.14 (~M1), U12.8 (~M1)
~MREQ: J1.42 (B11), U1.2 (I), U7.19 (~MREQ), U9.22 (~CS)
~NMI: J1.57 (B26), RN2.5 (R4), U7.17 (~NMI), U10.5
~RAM_OE: U1.19 (I/O), U9.24 (~OE)
~RD: J1.44 (B13), U1.5 (I), U7.21 (~RD), U8.24 (~OE), U11.6 (~RD), U12.32 (~RD)
~RESET: J1.33 (B2), U1.1 (I/CLK), U3.1 (~Mr), U7.26 (~RST), U10.12, U11.17 (~RST), U12.21 (~RST)
~ROM_CS: U1.20 (I/O), U8.22 (~CS), U10.1
~SIO_CS: U1.16 (I/O), U12.35 (~CE)
~WAIT: J1.49 (B18), RN2.4 (R3), U7.24 (~WAIT), U10.3
~WR: J1.45 (B14), U1.4 (I/PD), U7.22 (~WR), U8.31 (~PGM), U9.29 (~WE)

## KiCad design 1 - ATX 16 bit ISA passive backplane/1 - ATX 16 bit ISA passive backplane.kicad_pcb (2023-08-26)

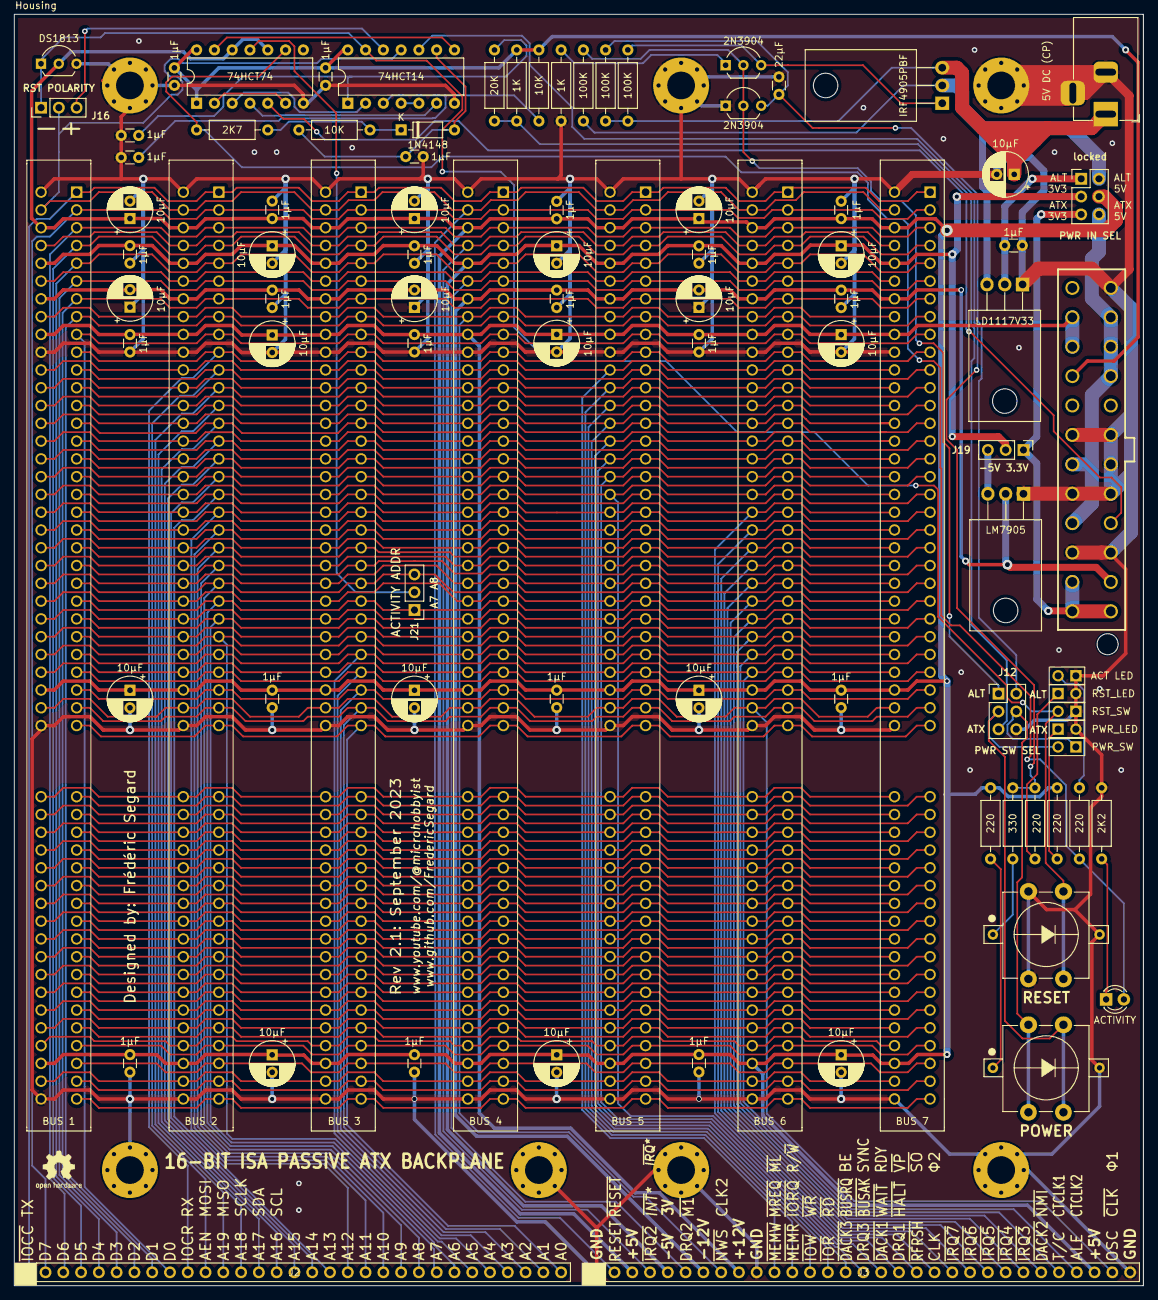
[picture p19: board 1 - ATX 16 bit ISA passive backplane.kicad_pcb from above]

Board: 2 copper layers, 161.3 x 181.6 mm, 102 parts (1 on the bottom side), 128 nets.

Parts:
C1, C2, C3, C4, C6, C8, C9, C10, C11, C13, C14, C15, C19, C24, C29, C31, C33, C35, C37: 10µF; CP_Radial_D6.3mm_P2.50mm
C5, C7, C12, C16, C17, C18, C20, C21, C22, C23, C25, C26, C27, C28, C30, C32, C34, C36, C38, C39, C42, C44, C45, C46: 1µF; C_Disc_D3.0mm_W1.6mm_P2.50mm
C41: 22µF; C_Disc_D3.0mm_W1.6mm_P2.50mm
D2: 1N4148; D_DO-35_SOD27_P7.62mm_Horizontal
D3: ACTIVITY; LED_D3.0mm
H1, H2, H3, H4, H5, H6, H7: MH; MountingHole_M3.96_Pad_Via_ATX
J1: BUS 1; ISA_Connector_98
J2: A: Component Side; PinHeader_1x31_P2.54mm_Vertical
J3: B: Back Side; PinHeader_1x31_P2.54mm_Vertical
J4: BUS 2; ISA_Connector_98
J5: BUS 3; ISA_Connector_98
J6: BUS 4; ISA_Connector_98
J7: BUS 5; ISA_Connector_98
J8: BUS 6; ISA_Connector_98
J9: BUS 7; ISA_Connector_98
J10: ATX POWER; ATX_PSU_CONN
J12: PWR SW SEL; PinHeader_2x03_P2.54mm_Vertical
J13: PWR_LED; PinHeader_1x2_Vertical (Modified)
J14: PWR_SW; PinHeader_1x2_Vertical (Modified)
J15: 5V DC (CP); BarrelJack_Horizontal
J16: RST POLARITY; PinHeader_1x03_P2.54mm_Vertical
J17: RST_LED; PinHeader_1x2_Vertical (Modified)
J18: RST_SW; PinHeader_1x2_Vertical (Modified)
J19: 3V/-5V; PinHeader_1x03_P2.54mm_Vertical
J20: ACT LED; PinHeader_1x2_Vertical (Modified)
J21: ACTIVITY ADDR; PinHeader_1x03_P2.54mm_Vertical
LOGO1, LOGO2: Logo_Open_Hardware_Small; OSHW-Logo2_7.3x6mm_SilkScreen
N1: Housing; ATX_Backplane
Q1: IRF4905PBF; TO-220-3_Horizontal_TabDown
Q2, Q3: 2N3904; TO-92_Inline_Wide
R1, R2, R11, R17: 220; R_Axial_DIN0207_L6.3mm_D2.5mm_P10.16mm_Horizontal
R3, R6, R7: 100K; R_Axial_DIN0207_L6.3mm_D2.5mm_P10.16mm_Horizontal
R4, R14: 10K; R_Axial_DIN0207_L6.3mm_D2.5mm_P10.16mm_Horizontal
R5, R8: 1K; R_Axial_DIN0207_L6.3mm_D2.5mm_P10.16mm_Horizontal
R9: 20K; R_Axial_DIN0207_L6.3mm_D2.5mm_P10.16mm_Horizontal
R10: 330; R_Axial_DIN0207_L6.3mm_D2.5mm_P10.16mm_Horizontal
R15: 2K7; R_Axial_DIN0207_L6.3mm_D2.5mm_P10.16mm_Horizontal
R16: 2K2; R_Axial_DIN0207_L6.3mm_D2.5mm_P10.16mm_Horizontal
RS1: DS1813; TO-92L_Inline_Wide
SW1: POWER; Pushbutton_12mm_LED
SW2: RESET; Pushbutton_12mm_LED
U1: 74HCT14; DIP-14_W7.62mm
U2: LD1117V33; TO-220-3_Horizontal_TabDown
U3: 74HCT74; DIP-14_W7.62mm
U4: LM7905; TO-220-3_Horizontal_TabDown
locked: PWR IN SEL; PinHeader_2x03_P2.54mm_Vertical

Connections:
+3V3: C4.1, C5.1, C6.1, C7.1, C11.1, C12.1, J1.36 (B5), J3.5, J4.36 (B5), J5.36 (B5), J6.36 (B5), J7.36 (B5), J8.36 (B5), J9.36 (B5), J19.2, locked.3
+5V: C1.1, C2.1, C3.1, C8.1, C9.1, C10.1, C13.1, C14.1, C15.1, C16.1, C17.1, C18.1, C21.1, C22.1, C23.1, C26.1, C27.1, C28.1, J1.34 (B3), J1.60 (B29), J1.96 (D16), J3.3, J3.29, J4.34 (B3), J4.60 (B29), J4.96 (D16), J5.34 (B3), J5.60 (B29), J5.96 (D16), J6.34 (B3), J6.60 (B29), J6.96 (D16), J7.34 (B3), J7.60 (B29), J7.96 (D16), J8.34 (B3), J8.60 (B29), J8.96 (D16), J9.34 (B3), J9.60 (B29), J9.96 (D16), R1.2, R2.2, RS1.2 (VCC), U3.10 (~S), U3.12 (D), locked.4
+12V: C19.1, C20.1, C24.1, C25.1, C29.1, C30.1, J1.40 (B9), J3.9, J4.40 (B9), J5.40 (B9), J6.40 (B9), J7.40 (B9), J8.40 (B9), J9.40 (B9), J10.10 (+12V), J10.11 (+12V)
-12V: C31.2, C32.1, C33.2, C34.1, C35.2, C36.1, J1.38 (B7), J3.7, J4.38 (B7), J5.38 (B7), J6.38 (B7), J7.38 (B7), J8.38 (B7), J9.38 (B7), J10.14 (-12V), U4.2 (VI)
/A0: J1.31 (A31), J2.31, J4.31 (A31), J5.31 (A31), J6.31 (A31), J7.31 (A31), J8.31 (A31), J9.31 (A31)
/A1: J1.30 (A30), J2.30, J4.30 (A30), J5.30 (A30), J6.30 (A30), J7.30 (A30), J8.30 (A30), J9.30 (A30)
/A2: J1.29 (A29), J2.29, J4.29 (A29), J5.29 (A29), J6.29 (A29), J7.29 (A29), J8.29 (A29), J9.29 (A29)
/A3: J1.28 (A28), J2.28, J4.28 (A28), J5.28 (A28), J6.28 (A28), J7.28 (A28), J8.28 (A28), J9.28 (A28)
/A4: J1.27 (A27), J2.27, J4.27 (A27), J5.27 (A27), J6.27 (A27), J7.27 (A27), J8.27 (A27), J9.27 (A27)
/A5: J1.26 (A26), J2.26, J4.26 (A26), J5.26 (A26), J6.26 (A26), J7.26 (A26), J8.26 (A26), J9.26 (A26)
/A6: J1.25 (A25), J2.25, J4.25 (A25), J5.25 (A25), J6.25 (A25), J7.25 (A25), J8.25 (A25), J9.25 (A25)
/A7: J1.24 (A24), J2.24, J4.24 (A24), J5.24 (A24), J6.24 (A24), J7.24 (A24), J8.24 (A24), J9.24 (A24), J21.1
/A8: J1.23 (A23), J2.23, J4.23 (A23), J5.23 (A23), J6.23 (A23), J7.23 (A23), J8.23 (A23), J9.23 (A23), J21.3
/A9: J1.22 (A22), J2.22, J4.22 (A22), J5.22 (A22), J6.22 (A22), J7.22 (A22), J8.22 (A22), J9.22 (A22)
/A10: J1.21 (A21), J2.21, J4.21 (A21), J5.21 (A21), J6.21 (A21), J7.21 (A21), J8.21 (A21), J9.21 (A21)
/A11: J1.20 (A20), J2.20, J4.20 (A20), J5.20 (A20), J6.20 (A20), J7.20 (A20), J8.20 (A20), J9.20 (A20)
/A12: J1.19 (A19), J2.19, J4.19 (A19), J5.19 (A19), J6.19 (A19), J7.19 (A19), J8.19 (A19), J9.19 (A19)
/A13: J1.18 (A18), J2.18, J4.18 (A18), J5.18 (A18), J6.18 (A18), J7.18 (A18), J8.18 (A18), J9.18 (A18)
/A14: J1.17 (A17), J2.17, J4.17 (A17), J5.17 (A17), J6.17 (A17), J7.17 (A17), J8.17 (A17), J9.17 (A17)
/A15: J1.16 (A16), J2.16, J4.16 (A16), J5.16 (A16), J6.16 (A16), J7.16 (A16), J8.16 (A16), J9.16 (A16)
/A16: J1.71 (C9), J4.71 (C9), J5.71 (C9), J6.71 (C9), J7.71 (C9), J8.71 (C9), J9.71 (C9)
/A17: J1.70 (C8), J4.70 (C8), J5.70 (C8), J6.70 (C8), J7.70 (C8), J8.70 (C8), J9.70 (C8)
/A18: J1.69 (C7), J4.69 (C7), J5.69 (C7), J6.69 (C7), J7.69 (C7), J8.69 (C7), J9.69 (C7)
/A19: J1.68 (C6), J4.68 (C6), J5.68 (C6), J6.68 (C6), J7.68 (C6), J8.68 (C6), J9.68 (C6)
/A20: J1.67 (C5), J4.67 (C5), J5.67 (C5), J6.67 (C5), J7.67 (C5), J8.67 (C5), J9.67 (C5)
/A21: J1.66 (C4), J4.66 (C4), J5.66 (C4), J6.66 (C4), J7.66 (C4), J8.66 (C4), J9.66 (C4)
/A22: J1.65 (C3), J4.65 (C3), J5.65 (C3), J6.65 (C3), J7.65 (C3), J8.65 (C3), J9.65 (C3)
/A23: J1.64 (C2), J4.64 (C2), J5.64 (C2), J6.64 (C2), J7.64 (C2), J8.64 (C2), J9.64 (C2)
/CLK: J1.51 (B20), J3.20, J4.51 (B20), J5.51 (B20), J6.51 (B20), J7.51 (B20), J8.51 (B20), J9.51 (B20)
/CLK2: J1.39 (B8), J3.8, J4.39 (B8), J5.39 (B8), J6.39 (B8), J7.39 (B8), J8.39 (B8), J9.39 (B8)
/CTCLK1: J1.58 (B27), J3.27, J4.58 (B27), J5.58 (B27), J6.58 (B27), J7.58 (B27), J8.58 (B27), J9.58 (B27)
/CTCLK2: J1.59 (B28), J3.28, J4.59 (B28), J5.59 (B28), J6.59 (B28), J7.59 (B28), J8.59 (B28), J9.59 (B28)
/D0: J1.9 (A9), J2.9, J4.9 (A9), J5.9 (A9), J6.9 (A9), J7.9 (A9), J8.9 (A9), J9.9 (A9)
/D1: J1.8 (A8), J2.8, J4.8 (A8), J5.8 (A8), J6.8 (A8), J7.8 (A8), J8.8 (A8), J9.8 (A8)
/D2: J1.7 (A7), J2.7, J4.7 (A7), J5.7 (A7), J6.7 (A7), J7.7 (A7), J8.7 (A7), J9.7 (A7)
/D3: J1.6 (A6), J2.6, J4.6 (A6), J5.6 (A6), J6.6 (A6), J7.6 (A6), J8.6 (A6), J9.6 (A6)
/D4: J1.5 (A5), J2.5, J4.5 (A5), J5.5 (A5), J6.5 (A5), J7.5 (A5), J8.5 (A5), J9.5 (A5)
/D5: J1.4 (A4), J2.4, J4.4 (A4), J5.4 (A4), J6.4 (A4), J7.4 (A4), J8.4 (A4), J9.4 (A4)
/D6: J1.3 (A3), J2.3, J4.3 (A3), J5.3 (A3), J6.3 (A3), J7.3 (A3), J8.3 (A3), J9.3 (A3)
/D7: J1.2 (A2), J2.2, J4.2 (A2), J5.2 (A2), J6.2 (A2), J7.2 (A2), J8.2 (A2), J9.2 (A2)
/D8: J1.73 (C11), J4.73 (C11), J5.73 (C11), J6.73 (C11), J7.73 (C11), J8.73 (C11), J9.73 (C11)
/D9: J1.74 (C12), J4.74 (C12), J5.74 (C12), J6.74 (C12), J7.74 (C12), J8.74 (C12), J9.74 (C12)
/D10: J1.75 (C13), J4.75 (C13), J5.75 (C13), J6.75 (C13), J7.75 (C13), J8.75 (C13), J9.75 (C13)
/D11: J1.76 (C14), J4.76 (C14), J5.76 (C14), J6.76 (C14), J7.76 (C14), J8.76 (C14), J9.76 (C14)
/D12: J1.77 (C15), J4.77 (C15), J5.77 (C15), J6.77 (C15), J7.77 (C15), J8.77 (C15), J9.77 (C15)
/D13: J1.78 (C16), J4.78 (C16), J5.78 (C16), J6.78 (C16), J7.78 (C16), J8.78 (C16), J9.78 (C16)
/D14: J1.79 (C17), J4.79 (C17), J5.79 (C17), J6.79 (C17), J7.79 (C17), J8.79 (C17), J9.79 (C17)
/D15: J1.80 (C18), J4.80 (C18), J5.80 (C18), J6.80 (C18), J7.80 (C18), J8.80 (C18), J9.80 (C18)
/MISO: J1.12 (A12), J2.12, J4.12 (A12), J5.12 (A12), J6.12 (A12), J7.12 (A12), J8.12 (A12), J9.12 (A12)
/MOSI: J1.11 (A11), J2.11, J4.11 (A11), J5.11 (A11), J6.11 (A11), J7.11 (A11), J8.11 (A11), J9.11 (A11)
/Power/ALT1: J12.1, Q2.2 (B), Q3.2 (B), R6.1
/Power/ALT2: C41.1, J12.2, Q3.3 (C), R7.1
/Power/ALT_3V3: C42.1, U2.2 (VO), locked.1
/Power/ALT_5V: Q1.2 (D), R6.2, U2.3 (VI), locked.2
/Power/ATX: J12.5, R8.2, R9.1
/Power/ATX_3V3: J10.1 (+3.3V), J10.2 (+3.3V), J10.13 (+3.3V), J19.1, locked.5
/Power/ATX_5V: J10.4 (+5V), J10.6 (+5V), J10.21 (+5V), J10.22 (+5V), J10.23 (+5V), locked.6
/Power/ATX_-5V: J19.3, U4.3 (VO)
/Power/Vin: C37.1, J15.1, Q1.3 (S), R3.2, R7.2
/Power/~PS_ON: J10.16 (~PS_ON), U3.5 (Q)
/Power/~PWR_UP: U1.6, U3.4 (~S)
/RX: J1.10 (A10), J2.10, J4.10 (A10), J5.10 (A10), J6.10 (A10), J7.10 (A10), J8.10 (A10), J9.10 (A10)
/RX2: J1.72 (C10), J4.72 (C10), J5.72 (C10), J6.72 (C10), J7.72 (C10), J8.72 (C10), J9.72 (C10)
/Reset & LEDs/+RST: J16.3, U1.12
/Reset & LEDs/-RST: J16.1, J18.2, RS1.1 (~RESET), SW2.2, U1.13
/SCL: J1.15 (A15), J2.15, J4.15 (A15), J5.15 (A15), J6.15 (A15), J7.15 (A15), J8.15 (A15), J9.15 (A15)
/SCLK: J1.13 (A13), J2.13, J4.13 (A13), J5.13 (A13), J6.13 (A13), J7.13 (A13), J8.13 (A13), J9.13 (A13)
/SDA: J1.14 (A14), J2.14, J4.14 (A14), J5.14 (A14), J6.14 (A14), J7.14 (A14), J8.14 (A14), J9.14 (A14)
/TX: J1.1 (A1), J2.1, J4.1 (A1), J5.1 (A1), J6.1 (A1), J7.1 (A1), J8.1 (A1), J9.1 (A1)
/TX2: J1.63 (C1), J4.63 (C1), J5.63 (C1), J6.63 (C1), J7.63 (C1), J8.63 (C1), J9.63 (C1)
/USR1: J1.89 (D9), J4.89 (D9), J5.89 (D9), J6.89 (D9), J7.89 (D9), J8.89 (D9), J9.89 (D9)
/USR2: J1.90 (D10), J4.90 (D10), J5.90 (D10), J6.90 (D10), J7.90 (D10), J8.90 (D10), J9.90 (D10)
/USR3: J1.91 (D11), J4.91 (D11), J5.91 (D11), J6.91 (D11), J7.91 (D11), J8.91 (D11), J9.91 (D11)
/USR4: J1.92 (D12), J4.92 (D12), J5.92 (D12), J6.92 (D12), J7.92 (D12), J8.92 (D12), J9.92 (D12)
/USR5: J1.93 (D13), J4.93 (D13), J5.93 (D13), J6.93 (D13), J7.93 (D13), J8.93 (D13), J9.93 (D13)
/USR6: J1.94 (D14), J4.94 (D14), J5.94 (D14), J6.94 (D14), J7.94 (D14), J8.94 (D14), J9.94 (D14)
/USR7: J1.95 (D15), J4.95 (D15), J5.95 (D15), J6.95 (D15), J7.95 (D15), J8.95 (D15), J9.95 (D15)
/USR8: J1.97 (D17), J4.97 (D17), J5.97 (D17), J6.97 (D17), J7.97 (D17), J8.97 (D17), J9.97 (D17)
/~BUSAK: J1.47 (B16), J3.16, J4.47 (B16), J5.47 (B16), J6.47 (B16), J7.47 (B16), J8.47 (B16), J9.47 (B16)
/~BUSRQ: J1.46 (B15), J3.15, J4.46 (B15), J5.46 (B15), J6.46 (B15), J7.46 (B15), J8.46 (B15), J9.46 (B15)
/~CLK: J1.61 (B30), J3.30, J4.61 (B30), J5.61 (B30), J6.61 (B30), J7.61 (B30), J8.61 (B30), J9.61 (B30)
/~HALT: J1.49 (B18), J3.18, J4.49 (B18), J5.49 (B18), J6.49 (B18), J7.49 (B18), J8.49 (B18), J9.49 (B18)
/~IORQ: J1.43 (B12), J3.12, J4.43 (B12), J5.43 (B12), J6.43 (B12), J7.43 (B12), J8.43 (B12), J9.43 (B12)
/~IRQ2: J1.35 (B4), J3.4, J4.35 (B4), J5.35 (B4), J6.35 (B4), J7.35 (B4), J8.35 (B4), J9.35 (B4)
/~IRQ3: J1.56 (B25), J3.25, J4.56 (B25), J5.56 (B25), J6.56 (B25), J7.56 (B25), J8.56 (B25), J9.56 (B25)
/~IRQ4: J1.55 (B24), J3.24, J4.55 (B24), J5.55 (B24), J6.55 (B24), J7.55 (B24), J8.55 (B24), J9.55 (B24)
/~IRQ5: J1.54 (B23), J3.23, J4.54 (B23), J5.54 (B23), J6.54 (B23), J7.54 (B23), J8.54 (B23), J9.54 (B23)
/~IRQ6: J1.53 (B22), J3.22, J4.53 (B22), J5.53 (B22), J6.53 (B22), J7.53 (B22), J8.53 (B22), J9.53 (B22)
/~IRQ7: J1.52 (B21), J3.21, J4.52 (B21), J5.52 (B21), J6.52 (B21), J7.52 (B21), J8.52 (B21), J9.52 (B21)
/~IRQ8: J1.81 (D1), J4.81 (D1), J5.81 (D1), J6.81 (D1), J7.81 (D1), J8.81 (D1), J9.81 (D1)
/~IRQ9: J1.82 (D2), J4.82 (D2), J5.82 (D2), J6.82 (D2), J7.82 (D2), J8.82 (D2), J9.82 (D2)
/~IRQ10: J1.83 (D3), J4.83 (D3), J5.83 (D3), J6.83 (D3), J7.83 (D3), J8.83 (D3), J9.83 (D3)
/~IRQ11: J1.84 (D4), J4.84 (D4), J5.84 (D4), J6.84 (D4), J7.84 (D4), J8.84 (D4), J9.84 (D4)
/~IRQ12: J1.85 (D5), J4.85 (D5), J5.85 (D5), J6.85 (D5), J7.85 (D5), J8.85 (D5), J9.85 (D5)
/~IRQ13: J1.86 (D6), J4.86 (D6), J5.86 (D6), J6.86 (D6), J7.86 (D6), J8.86 (D6), J9.86 (D6)
/~IRQ14: J1.87 (D7), J4.87 (D7), J5.87 (D7), J6.87 (D7), J7.87 (D7), J8.87 (D7), J9.87 (D7)
/~IRQ15: J1.88 (D8), J4.88 (D8), J5.88 (D8), J6.88 (D8), J7.88 (D8), J8.88 (D8), J9.88 (D8)
/~M1: J1.37 (B6), J3.6, J4.37 (B6), J5.37 (B6), J6.37 (B6), J7.37 (B6), J8.37 (B6), J9.37 (B6)
/~MREQ: J1.42 (B11), J3.11, J4.42 (B11), J5.42 (B11), J6.42 (B11), J7.42 (B11), J8.42 (B11), J9.42 (B11)
/~NMI: J1.57 (B26), J3.26, J4.57 (B26), J5.57 (B26), J6.57 (B26), J7.57 (B26), J8.57 (B26), J9.57 (B26)
/~RD: J1.45 (B14), J3.14, J4.45 (B14), J5.45 (B14), J6.45 (B14), J7.45 (B14), J8.45 (B14), J9.45 (B14)
/~RESET: J1.33 (B2), J3.2, J4.33 (B2), J5.33 (B2), J6.33 (B2), J7.33 (B2), J8.33 (B2), J9.33 (B2), J16.2, U1.11
/~RFSH: J1.50 (B19), J3.19, J4.50 (B19), J5.50 (B19), J6.50 (B19), J7.50 (B19), J8.50 (B19), J9.50 (B19)
/~WAIT: J1.48 (B17), J3.17, J4.48 (B17), J5.48 (B17), J6.48 (B17), J7.48 (B17), J8.48 (B17), J9.48 (B17)
/~WR: J1.44 (B13), J3.13, J4.44 (B13), J5.44 (B13), J6.44 (B13), J7.44 (B13), J8.44 (B13), J9.44 (B13)
GND: C1.2, C2.2, C3.2, C4.2, C5.2, C6.2, C7.2, C8.2, C9.2, C10.2, C11.2, C12.2, C13.2, C14.2, C15.2, C16.2, C17.2, C18.2, C19.2, C20.2, C21.2, C22.2, C23.2, C24.2, C25.2, C26.2, C27.2, C28.2, C29.2, C30.2, C31.1, C32.2, C33.1, C34.2, C35.1, C36.2, C37.2, C38.2, C39.2, C41.2, C42.2, C44.2, C45.2, C46.2, H1.1, H2.1, H3.1, H4.1, H5.1, H6.1, H7.1, J1.32 (B1), J1.41 (B10), J1.62 (B31), J1.98 (D18), J3.1, J3.10, J3.31, J4.32 (B1), J4.41 (B10), J4.62 (B31), J4.98 (D18), J5.32 (B1), J5.41 (B10), J5.62 (B31), J5.98 (D18), J6.32 (B1), J6.41 (B10), J6.62 (B31), J6.98 (D18), J7.32 (B1), J7.41 (B10), J7.62 (B31), J7.98 (D18), J8.32 (B1), J8.41 (B10), J8.62 (B31), J8.98 (D18), J9.32 (B1), J9.41 (B10), J9.62 (B31), J9.98 (D18), J10.3 (GND), J10.5 (GND), J10.7 (GND), J10.15 (GND), J10.17 (GND), J10.18 (GND), J10.19 (GND), J10.24 (GND), J12.6, J13.2, J15.2, J15.3, J17.2, J18.1, J20.1, Q3.1 (E), R5.1, R16.2, RS1.3 (GND), SW1.3 (K), SW2.1, SW2.3 (K), U1.7 (GND), U2.1 (GND), U3.7 (GND), U4.1 (GND)
unnamed: C38.1, R4.2, U1.3
unnamed: C39.1, R9.2, U1.1
unnamed: C46.1, D2.2 (A), R14.2, U1.9
unnamed: D2.1 (K), R14.1, R15.1
unnamed: D3.2 (A), R15.2, R17.1, U3.9 (Q)
unnamed: D3.1 (K), R16.1
unnamed: J12.3, J14.2, SW1.2
unnamed: J12.4, J14.1, SW1.1
unnamed: J13.1, R2.1
unnamed: J17.1, R11.1
unnamed: J20.2, R17.2
unnamed: J21.2, U3.11 (C)
unnamed: Q1.1 (G), Q2.3 (C), R3.1
unnamed: Q2.1 (E), R5.2
unnamed: R10.2, R11.2, U1.10
unnamed: R1.1, SW1.4 (A)
unnamed: R10.1, SW2.4 (A)
unnamed: U1.4, U1.5
unnamed: U1.2, U3.3 (C)
unnamed: U3.2 (D), U3.6 (~Q)
unnamed: U1.8, U3.13 (~R)
VCC: C44.1, C45.1, J10.9 (+5VSB), R4.1, R8.1, U1.14 (VCC), U3.1 (~R), U3.14 (VCC)

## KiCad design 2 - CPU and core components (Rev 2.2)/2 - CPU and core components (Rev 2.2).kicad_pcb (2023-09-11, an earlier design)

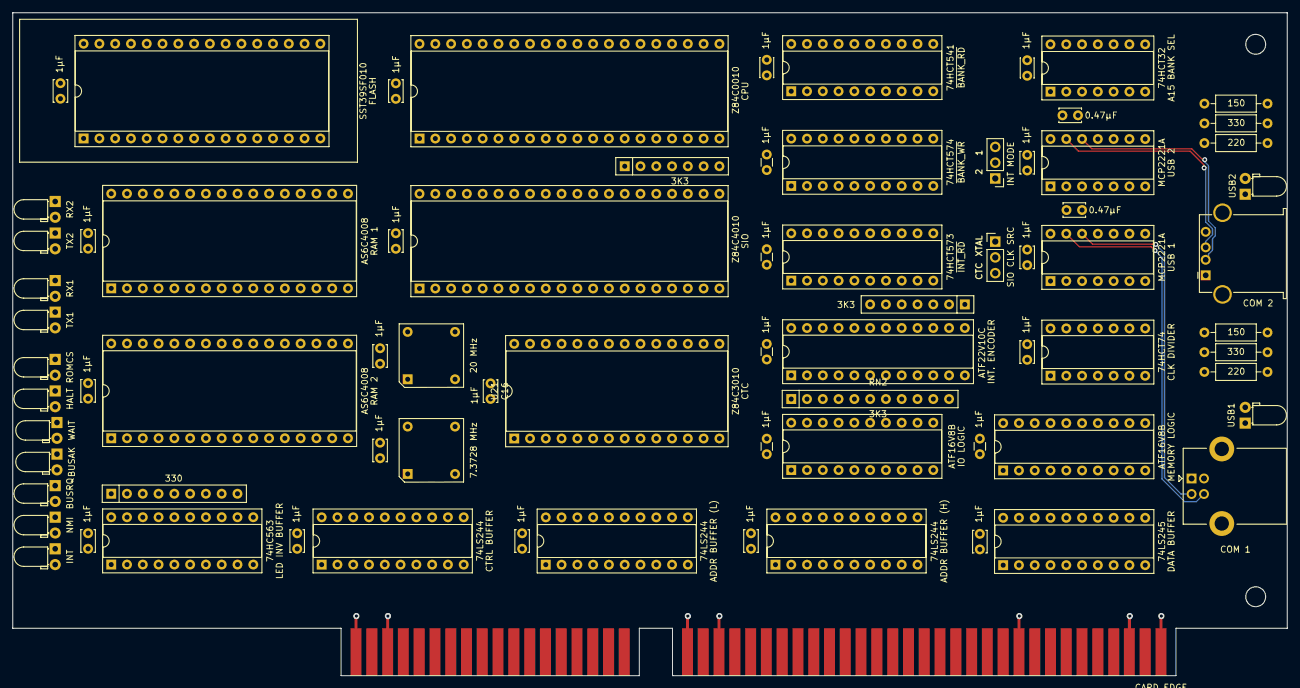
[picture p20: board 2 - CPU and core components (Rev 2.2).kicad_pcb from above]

Board: 4 copper layers, 205.1 x 106.7 mm, 76 parts (0 on the bottom side), 160 nets.

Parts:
C1, C2, C3, C4, C12, C13, C14, C15, C16, C17, C18, C19, C22, C23, C24, C25: 1µF; C_Disc_D3.4mm_W2.1mm_P2.50mm
C5, C6, C7, C10, C11: 1µF; C_Disc_D3.0mm_W1.6mm_P2.50mm
C8, C9: 1µF; C_Disc_D3.0mm_W2.0mm_P2.50mm
C20, C21: 0.47µF; C_Disc_D3.4mm_W2.1mm_P2.50mm
D1: INT; LED_D3.0mm_Horizontal_O1.27mm_Z2.0mm_Clear
D2: NMI; LED_D3.0mm_Horizontal_O1.27mm_Z2.0mm_Clear
D3: BUSRQ; LED_D3.0mm_Horizontal_O1.27mm_Z2.0mm_Clear
D4: BUSAK; LED_D3.0mm_Horizontal_O1.27mm_Z2.0mm_Clear
D5: WAIT; LED_D3.0mm_Horizontal_O1.27mm_Z2.0mm_Clear
D6: HALT; LED_D3.0mm_Horizontal_O1.27mm_Z2.0mm_Clear
D7: ROMCS; LED_D3.0mm_Horizontal_O1.27mm_Z2.0mm_Clear
D8: USB1; LED_D3.0mm_Horizontal_O1.27mm_Z2.0mm_Clear
D9: TX1; LED_D3.0mm_Horizontal_O1.27mm_Z2.0mm_Clear
D10: RX1; LED_D3.0mm_Horizontal_O1.27mm_Z2.0mm_Clear
D11: USB2; LED_D3.0mm_Horizontal_O1.27mm_Z2.0mm_Clear
D12: TX2; LED_D3.0mm_Horizontal_O1.27mm_Z2.0mm_Clear
D13: RX2; LED_D3.0mm_Horizontal_O1.27mm_Z2.0mm_Clear
J1: CARD EDGE; BUS_AT v2
J2: INT MODE; PinHeader_1x03_P2.54mm_Vertical
J3: COM 1; USB_B_Lumberg_2411_02_Horizontal
J4: COM 2; USB_A_Stewart_SS-52100-001_Horizontal
J5: SIO CLK SRC; PinHeader_1x03_P2.54mm_Vertical
R1, R4: 150; R_Axial_DIN0207_L6.3mm_D2.5mm_P10.16mm_Horizontal
R2, R5: 330; R_Axial_DIN0207_L6.3mm_D2.5mm_P10.16mm_Horizontal
R3, R6: 220; R_Axial_DIN0207_L6.3mm_D2.5mm_P10.16mm_Horizontal
RN1: 330; R_Array_SIP9
RN2: 3K3; R_Array_SIP11
RN3, RN4: 3K3; R_Array_SIP7
U1: 74HCT74; DIP-14_W7.62mm_Socket
U2: 74HC563; DIP-20_W7.62mm_Socket
U3, U4: ATF16V8B; DIP-20_W7.62mm_Socket
U5: 74HCT32; DIP-14_W7.62mm_Socket
U6: 74HCT574; DIP-20_W7.62mm_Socket
U7: 74HCT541; DIP-20_W7.62mm_Socket
U8: ATF22V10C; DIP-24_W7.62mm_Socket
U9: 74HCT573; DIP-20_W7.62mm_Socket
U10, U12, U13: 74LS244; DIP-20_W7.62mm_Socket
U11: Z84C0010; DIP-40_W15.24mm_Socket
U14: 74LS245; DIP-20_W7.62mm_Socket
U15: SST39SF010; DIP-32_W15.24mm_Socket
U16, U17: AS6C4008; DIP-32_W15.24mm_Socket
U18: Z84C4010; DIP-40_W15.24mm_Socket
U19, U20: MCP2221A; DIP-14_W7.62mm_Socket
U21: Z84C3010; DIP-28_W15.24mm_Socket
X1: 20 MHz; DIP-8-4_W7.62mm_Oscillator_Socket
X2: 7.3728 MHz; DIP-8-4_W7.62mm_Oscillator_Socket

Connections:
+5V: C1.1, C2.1, C3.1, C4.1, C5.1, C6.1, C7.1, C8.1, C9.1, C10.1, C11.1, C12.1, C13.1, C14.1, C15.1, C16.1, C17.1, C18.1, C19.1, C22.1, C23.1, C24.1, C25.1, D8.2 (A), D9.2 (A), D10.2 (A), D11.2 (A), D12.2 (A), D13.2 (A), J1.34 (B3), J1.60 (B29), J1.96 (D16), RN2.1 (common), RN3.1 (common), RN4.1 (common), U1.1 (~R), U1.4 (~S), U1.10 (~S), U1.13 (~R), U1.14 (VCC), U2.20 (VCC), U3.20 (VCC), U4.20 (VCC), U5.14 (VCC), U6.20 (VCC), U7.20 (VCC), U8.24 (VCC), U9.20 (VCC), U10.20 (VCC), U11.11 (VCC), U12.20 (VCC), U13.20 (VCC), U14.20 (VCC), U15.32 (VCC), U16.32 (VCC), U17.32 (VCC), U18.9 (VCC), U19.1 (VCC), U20.1 (VCC), U21.24 (VCC), X1.1 (EN), X1.8 (Vcc), X2.1 (EN), X2.8 (Vcc)
/CPU and Buffers/AA0: U11.30 (A0), U12.17 (I3b)
/CPU and Buffers/AA1: U11.31 (A1), U12.2 (I0a)
/CPU and Buffers/AA2: U11.32 (A2), U12.15 (I2b)
/CPU and Buffers/AA3: U11.33 (A3), U12.4 (I1a)
/CPU and Buffers/AA4: U11.34 (A4), U12.13 (I1b)
/CPU and Buffers/AA5: U11.35 (A5), U12.6 (I2a)
/CPU and Buffers/AA6: U11.36 (A6), U12.11 (I0b)
/CPU and Buffers/AA7: U11.37 (A7), U12.8 (I3a)
/CPU and Buffers/AA8: U10.17 (I3b), U11.38 (A8)
/CPU and Buffers/AA9: U10.2 (I0a), U11.39 (A9)
/CPU and Buffers/AA10: U10.15 (I2b), U11.40 (A10)
/CPU and Buffers/AA11: U10.4 (I1a), U11.1 (A11)
/CPU and Buffers/AA12: U10.13 (I1b), U11.2 (A12)
/CPU and Buffers/AA13: U10.6 (I2a), U11.3 (A13)
/CPU and Buffers/AA14: U10.11 (I0b), U11.4 (A14)
/CPU and Buffers/AA15: U10.8 (I3a), U11.5 (A15)
/CPU and Buffers/DD0: U11.14 (D0), U14.18 (B0)
/CPU and Buffers/DD1: U11.15 (D1), U14.17 (B1)
/CPU and Buffers/DD2: U11.12 (D2), U14.16 (B2)
/CPU and Buffers/DD3: U11.8 (D3), U14.15 (B3)
/CPU and Buffers/DD4: U11.7 (D4), U14.14 (B4)
/CPU and Buffers/DD5: U11.9 (D5), U14.13 (B5)
/CPU and Buffers/DD6: U11.10 (D6), U14.12 (B6)
/CPU and Buffers/DD7: U11.13 (D7), U14.11 (B7)
/CPU and Buffers/~CIORQ: U11.20 (~IORQ), U13.13 (I1b)
/CPU and Buffers/~CM1: U11.27 (~M1), U13.8 (I3a)
/CPU and Buffers/~CMREQ: U11.19 (~MREQ), U13.11 (I0b)
/CPU and Buffers/~CRD: U11.21 (~RD), U13.15 (I2b)
/CPU and Buffers/~CWR: U11.22 (~WR), U13.17 (I3b)
/SIO/D1+: J3.3 (D+), U19.13 (D+)
/SIO/D1-: J3.2 (D-), U19.12 (D-)
/SIO/D2+: J4.3 (D+), U20.13 (D+)
/SIO/D2-: J4.2 (D-), U20.12 (D-)
A0: J1.31 (A31), U12.3 (O3b), U15.12 (A0), U16.12 (A0), U17.12 (A0), U18.34 (B/~A), U21.18 (CS0)
A1: J1.30 (A30), U12.18 (O0a), U15.11 (A1), U16.11 (A1), U17.11 (A1), U18.33 (C/~D), U21.19 (CS1)
A2: J1.29 (A29), U4.5 (I), U12.5 (O2b), U15.10 (A2), U16.10 (A2), U17.10 (A2)
A3: J1.28 (A28), U4.6 (I), U12.16 (O1a), U15.9 (A3), U16.9 (A3), U17.9 (A3)
A4: J1.27 (A27), U4.7 (I), U12.7 (O1b), U15.8 (A4), U16.8 (A4), U17.8 (A4)
A5: J1.26 (A26), U4.8 (I), U12.14 (O2a), U15.7 (A5), U16.7 (A5), U17.7 (A5)
A6: J1.25 (A25), U4.9 (I), U12.9 (O0b), U15.6 (A6), U16.6 (A6), U17.6 (A6)
A7: J1.24 (A24), U4.11 (I/~OE), U12.12 (O3a), U15.5 (A7), U16.5 (A7), U17.5 (A7)
A8: J1.23 (A23), U10.3 (O3b), U15.27 (A8), U16.27 (A8), U17.27 (A8)
A9: J1.22 (A22), U10.18 (O0a), U15.26 (A9), U16.26 (A9), U17.26 (A9)
A10: J1.21 (A21), U10.5 (O2b), U15.23 (A10), U16.23 (A10), U17.23 (A10)
A11: J1.20 (A20), U10.16 (O1a), U15.25 (A11), U16.25 (A11), U17.25 (A11)
A12: J1.19 (A19), U10.7 (O1b), U15.4 (A12), U16.4 (A12), U17.4 (A12)
A13: J1.18 (A18), U10.14 (O2a), U15.28 (A13), U16.28 (A13), U17.28 (A13)
A14: J1.17 (A17), U10.9 (O0b), U15.29 (A14), U16.3 (A14), U17.3 (A14)
A15: J1.16 (A16), U3.5 (I), U5.1, U5.4, U5.9, U5.12, U10.12 (O3a), U15.3 (A15)
BA15: U5.3, U16.31 (A15), U17.31 (A15)
BA16: U5.6, U16.2 (A16), U17.2 (A16)
BA17: U5.8, U16.30 (A17), U17.30 (A17)
BA18: U5.11, U16.1 (A18), U17.1 (A18)
BUSAK: U3.13 (I/O), U10.1 (OEa), U10.19 (OEb), U12.1 (OEa), U12.19 (OEb), U13.1 (OEa), U13.19 (OEb), U14.19 (CE)
BUS_IEI: J1.46 (B15), RN4.7 (R6), U18.6 (IEI)
CLK: J1.51 (B20), U1.5 (Q), U11.6 (CLK), U18.20 (CLK), U21.15 (CLK)
CLK2: J1.39 (B8), J5.1, U1.9 (Q), U21.21 (CLK/TRG2), U21.22 (CLK/TRG1), U21.23 (CLK/TRG0)
CTCLK1: J5.3, U21.8 (ZC/TO1)
CTCLK2: J1.14 (A14), U21.9 (ZC/TO2)
CTC_IEI: RN4.6 (R5), U18.7 (IEO), U21.13 (IEI)
D0: J1.9 (A9), U6.2 (D0), U7.18 (Y0), U9.19 (Q0), U14.2 (A0), U15.13 (DQ0), U16.13 (DQ0), U17.13 (DQ0), U18.40 (D0), U21.25 (D0)
D1: J1.8 (A8), U6.3 (D1), U7.17 (Y1), U9.18 (Q1), U14.3 (A1), U15.14 (DQ1), U16.14 (DQ1), U17.14 (DQ1), U18.1 (D1), U21.26 (D1)
D2: J1.7 (A7), U6.4 (D2), U7.16 (Y2), U9.17 (Q2), U14.4 (A2), U15.15 (DQ2), U16.15 (DQ2), U17.15 (DQ2), U18.39 (D2), U21.27 (D2)
D3: J1.6 (A6), U6.5 (D3), U7.15 (Y3), U9.16 (Q3), U14.5 (A3), U15.17 (DQ3), U16.17 (DQ3), U17.17 (DQ3), U18.2 (D3), U21.28 (D3)
D4: J1.5 (A5), U6.6 (D4), U7.14 (Y4), U9.15 (Q4), U14.6 (A4), U15.18 (DQ4), U16.18 (DQ4), U17.18 (DQ4), U18.38 (D4), U21.1 (D4)
D5: J1.4 (A4), U6.7 (D5), U7.13 (Y5), U9.14 (Q5), U14.7 (A5), U15.19 (DQ5), U16.19 (DQ5), U17.19 (DQ5), U18.3 (D5), U21.2 (D5)
D6: J1.3 (A3), U6.8 (D6), U7.12 (Y6), U9.13 (Q6), U14.8 (A6), U15.20 (DQ6), U16.20 (DQ6), U17.20 (DQ6), U18.37 (D6), U21.3 (D6)
D7: J1.2 (A2), U6.9 (D7), U7.11 (Y7), U9.12 (Q7), U14.9 (A7), U15.21 (DQ7), U16.21 (DQ7), U17.21 (DQ7), U18.4 (D7), U21.4 (D7)
GND: C1.2, C2.2, C3.2, C4.2, C5.2, C6.2, C7.2, C8.2, C9.2, C10.2, C11.2, C12.2, C13.2, C14.2, C15.2, C16.2, C17.2, C18.2, C19.2, C20.2, C21.2, C22.2, C23.2, C24.2, C25.2, J1.32 (B1), J1.41 (B10), J1.62 (B31), J1.98 (D18), J3.4 (GND), J3.5 (Shield), J4.4 (GND), J4.5 (Shield), RN1.1 (common), U1.7 (GND), U2.1 (OE), U2.10 (GND), U2.11 (LE), U3.10 (GND), U3.11 (I/~OE), U4.10 (GND), U5.7 (GND), U6.1 (OE), U6.10 (GND), U7.10 (GND), U8.12 (GND), U9.2 (D0), U9.7 (D5), U9.8 (D6), U9.9 (D7), U9.10 (GND), U10.10 (GND), U11.29 (GND), U12.10 (GND), U13.2 (I0a), U13.4 (I1a), U13.6 (I2a), U13.10 (GND), U14.10 (GND), U15.1 (NC), U15.2 (A16), U15.16 (GND), U15.30 (NC), U16.16 (GND), U17.16 (GND), U18.18 (~CTSA), U18.19 (~DCDA), U18.22 (~DCDB), U18.23 (~CTSB), U18.31 (GND), U19.14 (GND), U20.14 (GND), U21.5 (GND), X1.4 (GND), X2.4 (GND)
unnamed: D1.2 (A), U2.19 (Q0)
unnamed: D1.1 (K), RN1.2 (R1)
unnamed: D2.2 (A), U2.18 (Q1)
unnamed: D2.1 (K), RN1.3 (R2)
unnamed: D3.2 (A), U2.17 (Q2)
unnamed: D3.1 (K), RN1.4 (R3)
unnamed: D4.2 (A), U2.16 (Q3)
unnamed: D4.1 (K), RN1.5 (R4)
unnamed: D5.2 (A), U2.15 (Q4)
unnamed: D5.1 (K), RN1.6 (R5)
unnamed: D6.2 (A), U2.14 (Q5)
unnamed: D6.1 (K), RN1.7 (R6)
unnamed: D7.2 (A), U2.13 (Q6)
unnamed: D7.1 (K), RN1.8 (R7)
unnamed: D8.1 (K), R1.1
unnamed: D9.1 (K), R2.1
unnamed: D10.1 (K), R3.1
unnamed: D11.1 (K), R4.1
unnamed: D12.1 (K), R5.1
unnamed: D13.1 (K), R6.1
unnamed: J2.2, U9.1 (OE)
unnamed: J5.2, U18.13 (~RxCA), U18.14 (~TxCA), U18.27 (~RxTxCB)
unnamed: U1.3 (C), X1.5 (OUT)
unnamed: U1.11 (C), X2.5 (OUT)
unnamed: U1.8 (~Q), U1.12 (D)
unnamed: U8.23 (I/O), U9.3 (D1)
unnamed: U8.22 (I/O), U9.4 (D2)
unnamed: U8.21 (I/O), U9.5 (D3)
unnamed: U8.20 (I/O), U9.6 (D4)
unnamed: U18.12 (RxDA), U19.6 (Tx_Out)
unnamed: U18.28 (RxDB), U20.6 (Tx_Out)
unnamed: U18.15 (TxDA), U19.5 (Rx_In)
unnamed: U18.26 (TxDB), U20.5 (Rx_In)
unnamed: R3.2, U19.2 (GP0_(Rx))
unnamed: R2.2, U19.3 (GP1_(Tx))
unnamed: R1.2, U19.7 (GP2_(USB))
unnamed: C20.1, U19.11 (VUSB)
unnamed: R6.2, U20.2 (GP0_(Rx))
unnamed: R5.2, U20.3 (GP1_(Tx))
unnamed: R4.2, U20.7 (GP2_(USB))
unnamed: C21.1, U20.11 (VUSB)
unnamed: U21.7 (ZC/TO0), U21.20 (CLK/TRG3)
RBA15: J1.71 (C9), U5.2, U6.19 (Q0), U7.2 (A0)
RBA16: J1.70 (C8), U5.5, U6.18 (Q1), U7.3 (A1)
RBA17: J1.69 (C7), U5.10, U6.17 (Q2), U7.4 (A2)
RBA18: J1.68 (C6), U5.13, U6.16 (Q3), U7.5 (A3)
RBA19: J1.67 (C5), U3.6 (I), U6.15 (Q4), U7.6 (A4)
RBA20: J1.66 (C4), U3.7 (I), U6.14 (Q5), U7.7 (A5)
RBA21: J1.65 (C3), U3.8 (I), U6.13 (Q6), U7.8 (A6)
RBA22: J1.64 (C2), U3.9 (I), U6.12 (Q7), U7.9 (A7)
RD: U4.17 (I/O), U14.1 (A->B)
~BANK_RD: U4.14 (I/O), U7.1 (G1), U7.19 (G2)
~BANK_WR: U4.15 (I/O), U6.11 (Cp)
~BUSAK: J1.48 (B17), U2.5 (D3), U3.12 (I/O), U11.23 (~BUSAK)
~BUSRQ: J1.47 (B16), RN4.2 (R1), U2.4 (D2), U11.25 (~BUSRQ)
~CLK: J1.61 (B30), U1.2 (D), U1.6 (~Q)
~CTC_CS: U4.18 (I/O), U21.16 (~CE)
~HALT: J1.50 (B19), U2.7 (D5), U11.18 (~HALT)
~INT: RN4.4 (R3), U2.2 (D0), U8.19 (I/O), U11.16 (~INT)
~IORQ: J1.43 (B12), U4.1 (I/CLK), U13.7 (O1b), U18.36 (~IORQ), U21.10 (~IORQ)
~IRQ0: RN2.2 (R1), U8.1 (I/CLK), U21.12 (~INT)
~IRQ1: RN2.3 (R2), U8.2 (I), U18.5 (~INT)
~IRQ2: J1.35 (B4), RN2.4 (R3), U8.3 (I)
~IRQ3: J1.56 (B25), RN2.5 (R4), U8.4 (I/PD)
~IRQ4: J1.55 (B24), RN2.6 (R5), U8.5 (I)
~IRQ5: J1.54 (B23), RN2.7 (R6), U8.6 (I)
~IRQ6: J1.53 (B22), RN2.8 (R7), U8.7 (I)
~IRQ7: J1.52 (B21), RN2.9 (R8), U8.8 (I)
~IRQ8: J1.81 (D1), RN2.10 (R9), U8.9 (I)
~IRQ9: J1.82 (D2), RN2.11 (R10), U8.10 (I)
~IRQ10: J1.83 (D3), RN3.4 (R3), U8.11 (I)
~IRQ11: J1.84 (D4), RN3.2 (R1), U8.13 (I)
~IRQ12: J1.85 (D5), RN3.3 (R2), U8.14 (I/O)
~IRQ13: J1.86 (D6), RN3.5 (R4), U8.15 (I/O)
~IRQ14: J1.87 (D7), RN3.6 (R5), U8.16 (I/O)
~IRQ15: J1.88 (D8), RN3.7 (R6), U8.17 (I/O)
~M1: J1.37 (B6), U4.2 (I), U9.11 (Load), U13.12 (O3a), U18.8 (~M1), U21.14 (~M1)
~MODE1: J2.3, U3.4 (I), U4.13 (I/O)
~MODE2: J2.1, U4.12 (I/O)
~MREQ: J1.42 (B11), U3.1 (I/CLK), U13.9 (O0b)
~NMI: J1.57 (B26), RN4.5 (R4), U2.3 (D1), U11.17 (~NMI)
~RAM1_CS: U3.17 (I/O), U16.22 (~CS)
~RAM2_CS: U3.16 (I/O), U17.22 (~CS)
~RAM_OE: J1.97 (D17), U3.18 (I/O), U16.24 (~OE), U17.24 (~OE)
~RD: J1.44 (B13), U3.2 (I), U4.4 (I), U13.5 (O2b), U15.24 (~OE), U18.32 (~RD), U21.6 (~RD)
~RESET: J1.33 (B2), U2.9 (D7), U3.3 (I), U11.26 (~RST), U18.21 (~RST), U21.17 (~RST)
~ROM_CS: U2.8 (D6), U3.19 (I/O), U15.22 (~CS)
~SIO_CS: U4.19 (I/O), U18.35 (~CE)
~WAIT: J1.49 (B18), RN4.3 (R2), U2.6 (D4), U11.24 (~WAIT)
~WR: J1.45 (B14), U4.3 (I), U13.3 (O3b), U15.31 (~PGM), U16.29 (~WE), U17.29 (~WE)

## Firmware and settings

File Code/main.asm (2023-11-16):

; --------------------------------------------------------------------------------------------------------------
;         :::::::::     ::::::::       :::::::            :::::::::     :::::::::::     ::::::::       :::::::: 
;             :+:     :+:    :+:     :+:   :+:           :+:    :+:        :+:        :+:    :+:     :+:    :+: 
;           +:+      +:+    +:+     +:+   +:+           +:+    +:+        +:+        +:+    +:+     +:+         
;         +#+        +#++:++#      +#+   +:+           +#++:++#+         +#+        +#+    +:+     +#++:++#++   
;       +#+        +#+    +#+     +#+   +#+           +#+    +#+        +#+        +#+    +#+            +#+    
;     #+#         #+#    #+#     #+#   #+#           #+#    #+#        #+#        #+#    #+#     #+#    #+#     
;   #########     ########       #######            #########     ###########     ########       ########       
; ------------------------------------------------------------------------------------------------------

; *********************************************************************************************************************
; * Z80 Project, code nema Fre80 (Freddy) by Frédéric Segard, a.k.a. MicroHobbyist
; * https://www.youtube.com/@microhobbyist
; * https://github.com/FredericSegard
; *
; * Copyright (C) 2023 Frédéric Segard
; *
; * This library is free software; you can redistribute it and/or modify it under the terms of the GNU Lesser General
; * Public License as published by the Free Software Foundation. You can use all or part of the code, regardless of
; * the version. But there is no warrenty of any kind.
; *
; * Reference:	ASCII text: https://www.messletters.com/en/big-text/ (alligator, standard)
; *				Editor tab-stops set to 4
; *				Assembler: VASM  (BIN: vasmz80_oldstyle -dotdir -chklabels -nocase %1.asm -Fbin -o %1.out -L %1.txt)
; *								 (HEX: vasmz80_oldstyle -dotdir -chklabels -nocase %1.asm -Fihex)
; * Version 0.7
; *********************************************************************************************************************


;   ____                         _                     _         
;  / ___|   ___    _ __    ___  | |_    __ _   _ __   | |_   ___ 
; | |      / _ \  | '_ \  / __| | __|  / _` | | '_ \  | __| / __|
; | |___  | (_) | | | | | \__ \ | |_  | (_| | | | | | | |_  \__ \
;  \____|  \___/  |_| |_| |___/  \__|  \__,_| |_| |_|  \__| |___/
;
; ---------------------------------------------------------------------------------------------------------------------
; VARIOUS CONSTANTS AND ADDRESSES USED IN THE CODE

; GENERAL EQUATES
NULL			= 0x00
CTRLC			= 0x03				; Control-C (Break)
CTRLG			= 0x07				; Control-G (Bell)
BKSP			= 0x08				; Backspace
TAB				= 0x09				; Horizontal tab
LF				= 0x0A				; Line-feed character
CS				= 0x0C				; Clear Screen
CR				= 0x0D				; Carriage-return character
CTRLO			= 0x0F				; Control "O"
CTRLQ			= 0x11				; Control "Q"
CTRLR			= 0x12				; Control "R"
CTRLS			= 0x13				; Control "S"
CTRLU			= 0x15				; Control "U"
ESC				= 0x1B				; Escape
SPACE			= 0x20				; Space character
DEL				= 0x7F				; Delete

DELIMITER		= " "				; Space delimiter between command line parameters
ERRORPTR		= "^"				; Error pointer symbol (used for pointing to the error position on command line)
QUOTE			= 0x22
JUMP			= 0xC3				; Delimiter for command list items (It's the actual jp command opcode)
HELP			= 0x0F
EOT				= 0xFF				; End of table

;PARAMETERS
HorizTextRes	= 40				; Horizontal text resolution (40 or 80)
VertTextRes		= 24				; Vertical text resolution (typical 24 or 25)
ErrorPtrOffset	= 9					; Take into account the command prompt width
BytesFree		= (VectorTable-EndOfCode)+(StartOfCode-InterruptVectorEnd)	; Base free bytes

; I/O ADDRESSES
SIO_PortA_Data	= 0x04				; SIO data port A
SIO_PortB_Data	= 0x05				; SIO data port B
SIO_PortA_Ctrl	= 0x06				; SIO control port A
SIO_PortB_Ctrl	= 0x07				; SIO control port B

BankSelect		= 0x30				; RAM bank select address (values (0x00 to 0xFF)
RomDisable		= 0x38				; ROM dissable address (any value)

; STATUS INDICATOR FLAGS (BIT NUMBER... 3 and 5 are not used
Carry			= 0					; (F) Carry flag
Negative		= 1					; (N) Add/substract flag
Parity			= 2					; (P) Parity flag (Same bit position as bellow, depends on the instruction)
Overflow		= 2					; (V) Overflow flag (Same bit position as above, depends on the instruction)
HalfCarry		= 4					; (H) Half-carry flag
Zero			= 6					; (Z) Zero flag
Sign			= 7					; (S) Sign flag


;  ___           _                                          _    __     __                _                        
; |_ _|  _ __   | |_    ___   _ __   _ __   _   _   _ __   | |_  \ \   / /   ___    ___  | |_    ___    _ __   ___ 
;  | |  | '_ \  | __|  / _ \ | '__| | '__| | | | | | '_ \  | __|  \ \ / /   / _ \  / __| | __|  / _ \  | '__| / __|
;  | |  | | | | | |_  |  __/ | |    | |    | |_| | | |_) | | |_    \ V /   |  __/ | (__  | |_  | (_) | | |    \__ \
; |___| |_| |_|  \__|  \___| |_|    |_|     \__,_| | .__/   \__|    \_/     \___|  \___|  \__|  \___/  |_|    |___/
;                                                  |_|                                                             
; ---------------------------------------------------------------------------------------------------------------------
; RESET AND INTERRUPT VECTORS (8-BYTE VECTORS EACH)

	.org	0x0000
	
RST00:								; Reset vector 0: Standard boot up reset vector
	jp		ShadowCopy				; Shadow copy BIOS and vectors
	ds		0x0008-$,0xFF

RST08:								; Reset Vector 1
	halt
	ds		0x0010-$,0xFF

RST10:								; Reset Vector 2
	halt
	ds		0x0018-$,0xFF
	
RST18:								; Reset Vector 3
	halt
	ds		0x0020-$,0xFF

RST20:								; Reset Vector 4
	halt
	ds		0x0028-$,0xFF

RST28:								; Reset Vector 5
	halt
	ds		0x0030-$,0xFF

RST30:								; Reset Vector 6
	halt
	ds		0x0038-$,0xFF

RST38:								; Reset vector 7: Interrupt Mode 1
	halt
	ds		0x0066-$,0xFF

NMI66:								; Non-masquable interreupt vector
	halt
	ds		0x0080-$,0xFF

InterruptVectorEnd:


;  ____    _                   _                         ____                         
; / ___|  | |__     __ _    __| |   ___   __      __    / ___|   ___    _ __    _   _ 
; \___ \  | '_ \   / _` |  / _` |  / _ \  \ \ /\ / /   | |      / _ \  | '_ \  | | | |
;  ___) | | | | | | (_| | | (_| | | (_) |  \ V  V /    | |___  | (_) | | |_) | | |_| |
; |____/  |_| |_|  \__,_|  \__,_|  \___/    \_/\_/      \____|  \___/  | .__/   \__, |
;                                                                      |_|      |___/ 
; ---------------------------------------------------------------------------------------------------------------------
; SHADOW COPY VECTORS AND BIOS FROM FLASH TO RAM

ShadowCopy:
	di								; Disable interrupts
	
; COPY INTERRUPT VECTORS TO ALL BANKS
	ld		A,0x0E					; Starting bank number
BankCopyLoop:						; Loop to copy reset vectors to all banks
	out		(BankSelect),A			; Sets bank number to value in accumulator
	; Perform vector copy
	ld      HL,0x0000				; Set start at address 0x0000 (ROM)
	ld      DE,0x0000				; Set destination address (RAM)
	ld      BC,InterruptVectorEnd	; Set counter to copy the interrupt vector table only
	ldir							; Copy, paste, and repeat, until the end of BC has been reached
	; Check for next iteration
	dec		A						; Decrement accumulator to move on to next bank
	cp		0xFF						; Has accumulator reached the end of the loop (past zero)?
	jr		nz,BankCopyLoop			; If not then do next bank the loop, else Bank 0 is already pre-selected
	ld		(CurrentBank),A			; Save Current Bank

; COPY THE BIOS TO RAM
ROMCopy:
    ld      HL,StartOfCode			; Source address
    ld      DE,StartOfCode			; Destination address
    ld      BC,EndOfCode-StartOfCode; Bytes to copy
    ldir							; Copy, paste, and repeat, until the range has been reached

; COPY THE VECTORS AND BLANK STACK TO RAM
VectorCopy:
    ld      HL,VectorTable			; Source address
    ld      DE,VectorTable			; Destination address
    ld      BC,0xFFFF-VectorTable	; Bytes to copy
    ldir							; Copy, paste, and repeat, until the range has been reached

	jp		StartOfCode

	ds		StartOfCode-$,0xFF		; Fill the rest of memory to start of code with 0xFF for fast FLASH programming


;  ___           _   _     _           _   _              
; |_ _|  _ __   (_) | |_  (_)   __ _  | | (_)  ____   ___ 
;  | |  | '_ \  | | | __| | |  / _` | | | | | |_  /  / _ \
;  | |  | | | | | | | |_  | | | (_| | | | | |  / /  |  __/
; |___| |_| |_| |_|  \__| |_|  \__,_| |_| |_| /___|  \___|
;
; ---------------------------------------------------------------------------------------------------------------------
; START OF CODE

	.org	0x8000					; Start of code at beginning of high memory

StartOfCode:
	ld		A,0
	out		(RomDisable),A			; Disable the ROM
	ld      SP,0xFFFF				; Set top of stack pointer to page FF
	
	call	SIO_Init				; Initializes the SIO

	; Print Boot message with bytes free
	call	ClearScreen				; Clear the terminal screen (with ANSI codes)
	ld		HL,BootMsg
	call	PrintString				; Print first line of boot message
	call	PrintLine				; Print a separator line
	call	PrintString				; Print second line of boot message
	push	HL
	ld		HL,BytesFree			; Load the amount of bytes free
	call	PrintDec
	pop		HL
	call	PrintString

	ld		HL,0x0000				; Set default current address
	ld		(CurrentAddress),HL		; Save in CurrentAddress variable
	ld		A,0
	out		(BankSelect),A			; Set the bank to number 0
	ld		(CurrentBank),A			; Save the Current Bank

	; Clear the registers
	ld		A,0
	ld		BC,0
	ld		DE,0
	ld		HL,0
	ld		IX,0
	ld		IY,0
	push	BC						; LSB to clear the flag
	pop		AF						; Clear flag

;	ei								; Enable interrupts


;  __  __           _         
; |  \/  |   __ _  (_)  _ __  
; | |\/| |  / _` | | | | '_ \ 
; | |  | | | (_| | | | | | | |
; |_|  |_|  \__,_| |_| |_| |_|
;
; ----------------------------
; MAIN LOOP

Main:
	call	CommandPrompt			; Print the command prompt (0000>)
	
	push	BC
	push	HL
	
	ld		B,30					; Set the maximum number of bytes to read
	ld		HL,CommandBuffer		; Set the memory area to read the string to
	call	ReadString				; Read a string from console (HL is the address of buffer, BC is character count)
	
	pop		HL
	pop		BC
	
	call	Parser					; Parse the entered command
	
	jr		Main


;  ____            _                              _     _                      
; / ___|   _   _  | |__    _ __    ___    _   _  | |_  (_)  _ __     ___   ___ 
; \___ \  | | | | | '_ \  | '__|  / _ \  | | | | | __| | | | '_ \   / _ \ / __|
;  ___) | | |_| | | |_) | | |    | (_) | | |_| | | |_  | | | | | | |  __/ \__ \
; |____/   \__,_| |_.__/  |_|     \___/   \__,_|  \__| |_| |_| |_|  \___| |___/
;
; ---------------------------------------------------------------------------------------------------------------------
; ALL SUBROUTINES ARE EMBEDED IN VARIOUS INCLUDE FILES

	.include	"io.asm"			; Input and output subroutines
	.include	"convert.asm"		; Convert and process data subroutines
	.include	"monitor.asm"		; Monitor command subroutines
	.include	"ancillary.asm"		; Anscillary subroutines for monitor commands
	.include	"basic.asm"			; Nascom Microsoft Basic (from Grant Searle)
	.include	"data.asm"			; Various data and text messages. Keep last in list of includes


; __     __                 _           _       _              
; \ \   / /   __ _   _ __  (_)   __ _  | |__   | |   ___   ___ 
;  \ \ / /   / _` | | '__| | |  / _` | | '_ \  | |  / _ \ / __|
;   \ V /   | (_| | | |    | | | (_| | | |_) | | | |  __/ \__ \
;    \_/     \__,_| |_|    |_|  \__,_| |_.__/  |_|  \___| |___/
;
; ---------------------------------------------------------------------------------------------------------------------
; VARIABLES ARE DECLARED IN BYTE SIZE

CommandBuffer:		ds	HorizTextRes; Command prompt buffer
BufferPointer:		ds	2			; Buffer pointer
CmdErrorPointer:	ds	1			; Command line error pointer
CurrentBank:		ds	1			; Keep track of current bank
CurrentAddress:		ds	2			; Current Address for prompt
CurrentPort:		ds	1			; Current I/O port
DigitString			ds	9			; Digit string for numeric conversions (so they are printable with PrintString)
ParseSaveHL			dw	2			; Saves the HL, as HL is used to call routines, and interferes with registers
RegA:				ds	1			; Register A
RegBC:				ds	2			; Register BC
RegDE:				ds	2			; Register DE
RegHL:				ds	2			; Register HL
RegIX:				ds	2			; Index IX
RegIY:				ds	2			; Index IY
StackPtr:			ds	2			; Index SP
FlagsReg:			ds	1			; Status flags
;RegI:				ds	1			; 
;RegR:				ds	1			; 
StartAddress:		ds	2			; Original start or source address
EndAddress:			ds	2			; Original end or destination address
StartAddressAlt:	ds	2			; Original start or source address
EndAddressAlt: 		ds	2			; Original end or destination address
ByteTransfer:		ds	1			; Byte to copy/transfer
UserCodeSize:		ds	2			; Size of uploaded user code

EndOfCode:
	ds	VectorTable-$,0xFF			; Fill gap with 0xFF to optimize speed when programming the FLASH/EEPROM


; __     __                _                      _____           _       _        
; \ \   / /   ___    ___  | |_    ___    _ __    |_   _|   __ _  | |__   | |   ___ 
;  \ \ / /   / _ \  / __| | __|  / _ \  | '__|     | |    / _` | | '_ \  | |  / _ \
;   \ V /   |  __/ | (__  | |_  | (_) | | |        | |   | (_| | | |_) | | | |  __/
;    \_/     \___|  \___|  \__|  \___/  |_|        |_|    \__,_| |_.__/  |_|  \___|
;
; ---------------------------------------------------------------------------------------------------------------------
; CONSTANT VALUES SO EXTERNALLY LOADED PROGRAMS CAN ACCESS SPECIFIC INFORMATION
	.org	0xFD00

VectorTable:

IntVectorEnd:		dw	InterruptVectorEnd	;= 0xFD00			; End of interrupt vector table
VectorTableStart:	dw	VectorTable			;= 0xFD02			; Start of vector and jump tables
CodeStartAddr:		dw	StartOfCode			;= 0xFD04			; Start of code address
CodeEndAddr:		dw	EndOfCode			;= 0xFD06			; End of code address

	ds	JumpTable-$,0xFF				; 0xFF up to the jump table


;      _                                 _____           _       _        
;     | |  _   _   _ __ ___    _ __     |_   _|   __ _  | |__   | |   ___ 
;  _  | | | | | | | '_ ` _ \  | '_ \      | |    / _` | | '_ \  | |  / _ \
; | |_| | | |_| | | | | | | | | |_) |     | |   | (_| | | |_) | | | |  __/
;  \___/   \__,_| |_| |_| |_| | .__/      |_|    \__,_| |_.__/  |_|  \___|
;                             |_|                                         
; ---------------------------------------------------------------------------------------------------------------------
; JUMP TABLE TO CALL ROUTINES FROM AN EXTERNAL PROGRAM

	.org	0xFE00
	
JumpTable:
	jp		Ascii2HexNibble		;= 0xFE00				; [A -> A][A -> A]
	jp		Ascii2HexByte		;= 0xFE03				; [(HL) -> A][(HL) -> A]
	jp		Ascii2HexWord		;= 0xFE06				; [(HL) -> BC][(HL) -> BC]
	jp		ClearScreen			;= 0xFE09				; [][]
	jp		GetHexParameter		;= 0xFE0C				; [(HL) -> BC,A,(HL)][(HL) -> BC,A,(HL)]
	jp		PrintChar			;= 0xFE0F				; [A ->][A ->]
	jp		PrintString			;= 0xFE12				; [HL ->][HL ->]
	jp		PrintCRLF			;= 0xFE15				; [][]
	jp		PrintNibble			;= 0xFE18				; [A ->][A ->]
	jp		PrintByte			;= 0xFE1B				; [A ->][A ->]
	jp		PrintWord			;= 0xFE1E				; [HL ->][HL ->]
	jp		RangeValidation		;= 0xFE21				; Start&EndAddress -> C, Start&EndAddress, Start&EndAddressAlt)
	jp		ReadChar			;= 0xFE24				; [-> A][-> A]
	jp		ReadCharNoWait		;= 0xFE27
	jp		ReadString			;= 0xFE2A				; [HL ->][HL ->]
	jp		ReadByte			;= 0xFE2D				; [-> A][-> A]
	jp		ReadWord			;= 0xFE30				; [-> HL][-> HL]
	jp		SkipSpaces			;= 0xFE33				; [HL -> HL][HL -> HL]
	jp		UpperCase			;= 0xFE36				; [A -> A][A -> A]
	jp		Registers			;= 0xFE39				; [][]
	jp		Dec2Hex				;= 0xFE3C				; [(HL) -> BC]

VectorEnd:
	ds		StackPage-$,0xFF		; 0xFF the rest of the jump table all the way to the stack area


;  ____    _                    _    
; / ___|  | |_    __ _    ___  | | __
; \___ \  | __|  / _` |  / __| | |/ /
;  ___) | | |_  | (_| | | (__  |   < 
; |____/   \__|  \__,_|  \___| |_|\_\
;
; ---------------------------------------------------------------------------------------------------------------------
; STACK AREA, ClEAR OUT WITH ZEROS

	.org	0xFF00

StackPage:

	ds		0xFFFF-$,0x00			; Zero the stack all the way to end of ROM

BiosEnd:
.end

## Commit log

2023-08-15 First commit: Backplane almost finalized, and CPU & core peripherals card
    The backplane has some cleanup to be done with the PCB tracks. And I'm still in the process of designing the CPU with core peripherals card.
    [1 - ATX 16 bit ISA passive backplane.kicad_pcb, 1 - ATX 16 bit ISA passive backplane.kicad_sch, 2 - CPU and memory card with the essential peripherals.kicad_pc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]
2023-08-15 Cleaned up the PCB and ploted the gerber and schematic
    [1 - ATX 16 bit ISA passive backplane-B_Cu.gbl, 1 - ATX 16 bit ISA passive backplane-B_Mask.gbs, 1 - ATX 16 bit ISA passive backplane-B_Paste.gbp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]
2023-08-15 Added existing assembler code and PLD files
    [GlueLogic.kicad_sch, PS2.kicad_sch]
2023-08-16 Removed unessential components and added capacitors on the bus lanes. Still need work for on the silkscreen side.
    [1 - ATX 16 bit ISA passive backplane.kicad_pcb, 1 - ATX 16 bit ISA passive backplane.kicad_sch, ResetCircuit.kicad_sch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]
2023-08-17 Finished the silkscreen and outputed the Gerber
    [1 - ATX 16 bit ISA passive backplane-B_Cu.gbl, 1 - ATX 16 bit ISA passive backplane-B_Mask.gbs, 1 - ATX 16 bit ISA passive backplane-B_Paste.gbp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]
2023-08-19 Work in progress... don't mind the mess! It will be cleaned up shortly.
    [2 - CPU and memory card with the essential peripherals.kicad_pcb, 2 - CPU and memory card with the essential peripherals.kicad_sch, 2 - CPU and memory card wit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]
2023-08-19 Minor tweaks to the backplane, and will be sending it out for manufacture
    [1 - ATX 16 bit ISA passive backplane-B_Cu.gbl, 1 - ATX 16 bit ISA passive backplane-B_Mask.gbs, 1 - ATX 16 bit ISA passive backplane-B_Paste.gbp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]
2023-08-21 Updated disk activity circuit in mother board, and improved layout in CPU card
    [1 - ATX 16 bit ISA passive backplane-B_Cu.gbl, 1 - ATX 16 bit ISA passive backplane-B_Mask.gbs, 1 - ATX 16 bit ISA passive backplane-B_Paste.gbp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]
2023-08-22 Trying to hash out the flaws
    [1 - ATX 16 bit ISA passive backplane.kicad_pcb, 1 - ATX 16 bit ISA passive backplane.kicad_sch, 2 - CPU and memory card with the essentials (rev 2).kicad_sch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]
2023-08-26 Finally finalized the backplane to my liking.
    [1 - ATX 16 bit ISA passive backplane-B_Cu.gbl, 1 - ATX 16 bit ISA passive backplane-B_Mask.gbs, 1 - ATX 16 bit ISA passive backplane-B_Paste.gbp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]
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2023-08-28 Finished the schematic. Laying out the board (WiP)
    [2 - CPU and core components (Rev 2).dsn, 2 - CPU and core components (Rev 2).kicad_pcb, 2 - CPU and core components (Rev 2).kicad_sch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]
2023-08-29 Replacing a lot of TTL chips by 2 PLDs. Also, added blinkenlights.
    [2 - CPU and core components (Rev 2).dsn, 2 - CPU and core components (Rev 2).kicad_pcb, 2 - CPU and core components (Rev 2).kicad_sch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]
2023-08-29 Removed rev1 from the repo. Keeping only rev2
    [2 - CPU and memory card with the essentials (rev 2).kicad_pcb, 2 - CPU and memory card with the essentials (rev 2).kicad_sch, Blinkenlights.kicad_sch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]
2023-08-29 Cleaned up unnecessary files from the repo
    [2 - CPU and core components (Rev 2).dsn, 2 - CPU and core components (Rev 2).kicad_sch, GlueLogic.kicad_sch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]
2023-08-31 Added Interrupt Enable daisy chain jumpers between the ISA slots
    [1 - ATX 16 bit ISA passive backplane-B_Cu.gbl, 1 - ATX 16 bit ISA passive backplane-B_Mask.gbs, 1 - ATX 16 bit ISA passive backplane-B_Paste.gbp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]
2023-08-31 Finished component placement, currently routing.
    [2 - CPU and core components (Rev 2).dsn, 2 - CPU and core components (Rev 2).kicad_pcb, Blinkenlights.kicad_sch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]
2023-09-03 Removed the alternate power input.
    The soft power on circuit was flaky upon testing.
    [1 - ATX 16 bit ISA passive backplane-B_Cu.gbl, 1 - ATX 16 bit ISA passive backplane-B_Mask.gbs, 1 - ATX 16 bit ISA passive backplane-B_Paste.gbp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]
2023-09-03 Adding buffers to the CPU card
    [2 - CPU and core components (Rev 2).kicad_pcb, 2 - CPU and core components (Rev 2.1).kicad_pcb, 2 - CPU and core components (Rev 2.1).kicad_sch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]
2023-09-03 Updated the gerber to reflect the changes
    [1 - ATX 16 bit ISA passive backplane-B_Cu.gbl, 1 - ATX 16 bit ISA passive backplane-B_Mask.gbs, 1 - ATX 16 bit ISA passive backplane-B_Paste.gbp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]
2023-09-03 Removing unnecessary Spectra file
    [1 - ATX 16 bit ISA passive backplane.dsn]
2023-09-03 Removed unbuffered rev 2 iteration. keeping only rev 2.1
    [2 - CPU and core components (Rev 2).dsn, 2 - CPU and core components (Rev 2).kicad_pcb, 2 - CPU and core components (Rev 2).kicad_sch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]
2023-09-05 Trying to work out the PLD logic
    [2 - CPU and core components (Rev 2.1).kicad_sch, CPUandMemory.kicad_sch, CTC.kicad_sch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]
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2023-09-11 Still deciding on the components that will be on the core card.
    [2 - CPU and core components (Rev 2.1).kicad_pcb, 2 - CPU and core components (Rev 2.1).kicad_sch, 2 - CPU and core components (Rev 2.2).dsn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]
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2023-09-24 Archived rev 2.2 in favor of rev 3.
    [2 - CPU and core components (Rev 2.2)-B_Cu.gbl, 2 - CPU and core components (Rev 2.2)-B_Mask.gbs, 2 - CPU and core components (Rev 2.2)-B_Paste.gbp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]
2023-09-24 Compacted board to 100mm² PCB, where rev 2.2 was much bigger
    [1 - Main CPU board with basic peripherals (rev6).dsn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]
